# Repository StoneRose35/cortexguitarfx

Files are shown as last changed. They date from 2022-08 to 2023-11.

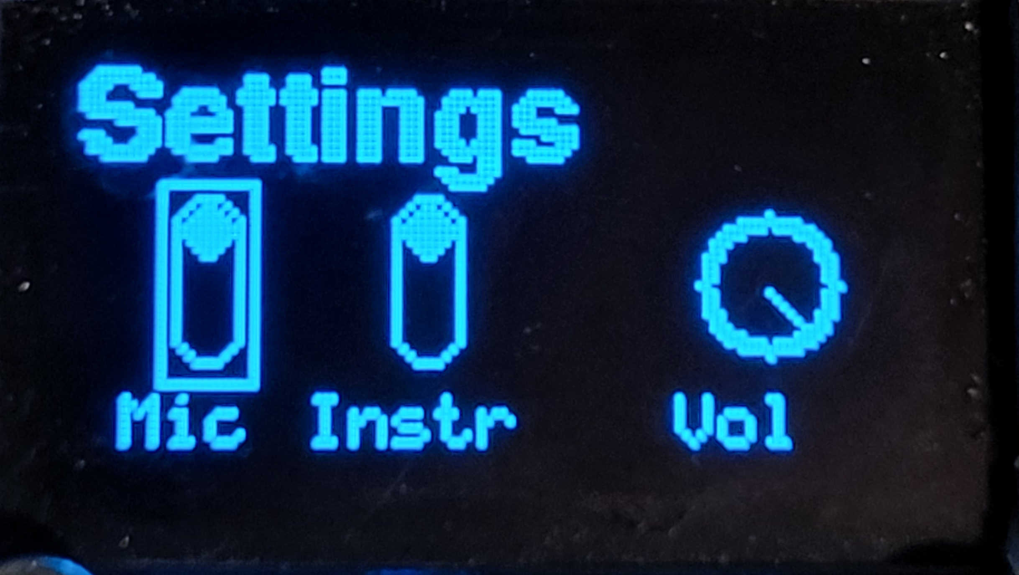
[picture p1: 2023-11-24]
Doc/manual/images/level5_select_settings_f.jpg

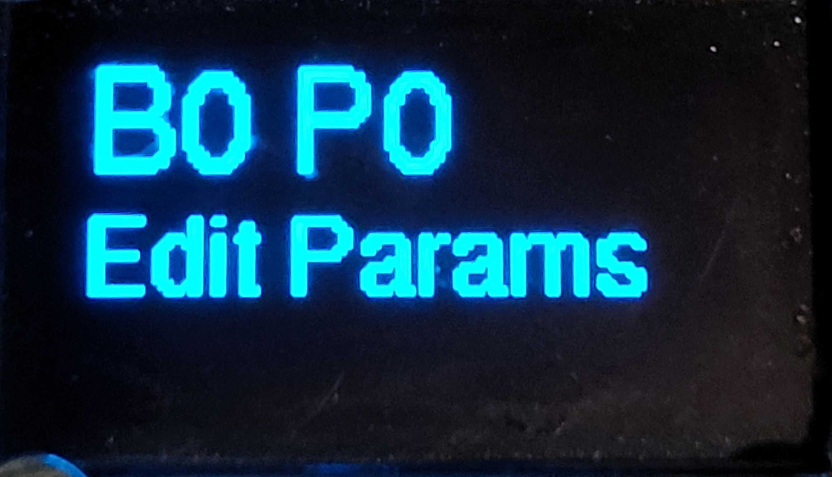
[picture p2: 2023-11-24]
Doc/manual/images/params_edit_f.jpg

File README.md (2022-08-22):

# cortexguitarfx
guitar effects processor implemented on various arm cortex platforms
Contains the following hardware elements:
* ARM Cortex M Microprocessor
* I2S Interface 
* Three potentiometers
* SSD1306-based 128x64 Pixel OLED Display
* Two pushbuttons: 'Enter' and 'Exit'
* rotary encoder
* analog pre- and postprocessor: guitar preamp and postgain amp

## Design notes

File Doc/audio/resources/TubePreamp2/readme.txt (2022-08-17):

Overdriven.fr - Free Guitar Cab Impulse Responses
-------------------------------------------------
This directory contains free guitar contains impulse responses from overdriven.fr (https://overdriven.fr). Visit https://overdriven.fr/overdriven/index.php/irdownloads/ for IR capture information.

Collection Version : 1.0

Cab 		: German 112 (1*12)
Speaker 	: Celestion(r) G12-65, 8 ohms
Power amp 	: KT88 
Mic preamp	: TubePreamp2

Microphones : 11
IR files    : 98

Microphones included : DYN-57 DYN-US-6 DYN-AT-1 DYN-AT-2 DYN-R20 RBN-DE-2 RBN-CN-1 RBN-CN-2 DYN-I5 DYN-7B DYN-CN-7 

Format is WAV 44,1 kHz, 32 bits floating point. IRs length is 50 milliseconds . 

Terms of use
------------
Overdriven.fr provides free audio impulse response files. These files remain the entire property of overdriven.fr / David. A. THESE FILES ARE PROVIDED « AS-IS ». overdriven.fr SHALL NOT BE LIABLE FOR ANY INDIRECT, SPECIAL, INCIDENTAL, CONSEQUENTIAL OR EXEMPLARY DAMAGES OR LOSSES ARISING FROM THE USE OF, INABILITY TO USE THE impulse response files. THESE EXCLUSIONS APPLY TO ANY CLAIMS FOR LOST PROFITS, LOST DATA, LOSS OF GOODWILL, WORK STOPPAGE, COMPUTER FAILURE OR MALFUNCTION, OR ANY OTHER COMMERCIAL DAMAGES OR LOSSES, EVEN IF OVERDRIVEN.FR KNEW OR SHOULD HAVE KNOWN OF THE POSSIBILITY OF SUCH DAMAGES 

Users are free to use these impulse files in the context of musical or video creations, free of rights, and this for any commercial or non-commercial purpose. 

It is expressly forbidden to host these files on other websites, or through any file sharing systems. Reselling these files is forbidden. Audio software or hardware vendors are not allowed to distribute these files with their products without a written agreement from the owner of overdriven.fr. 

Generated : dim. mars 06 16:51:21 CET 2022

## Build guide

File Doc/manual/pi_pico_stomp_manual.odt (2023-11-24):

PiPicoFX Stomp Manual

Overview

Analog Gain for Mic and Intrument

Quickdials (only functional in Live mode)

Output clipping

Input clipping

Screen

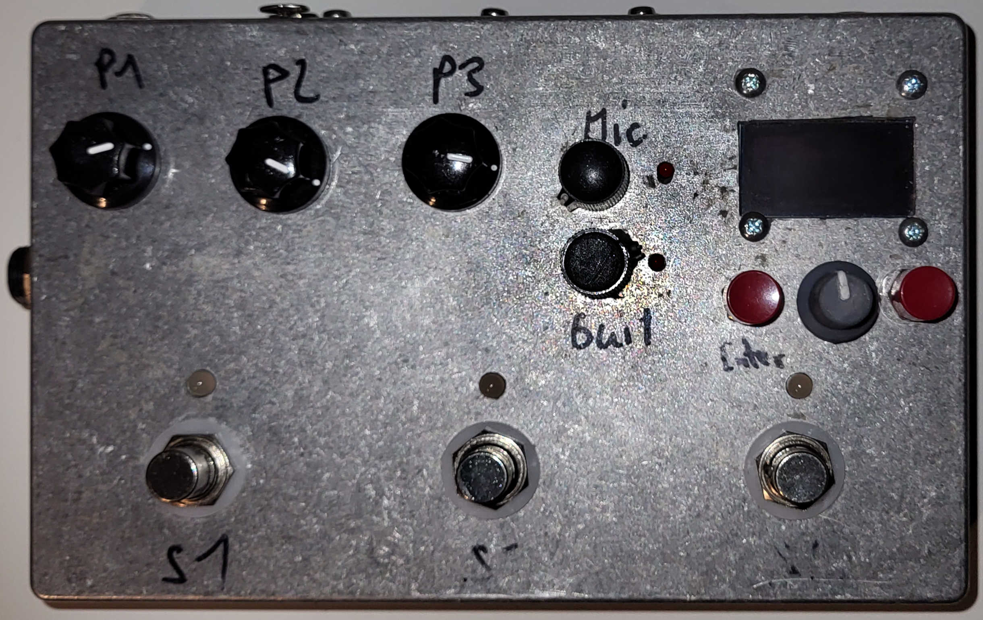
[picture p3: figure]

Power Connector

(12V~)

Stompswitches and LED’s

Enter

Exit

Rotary Dial

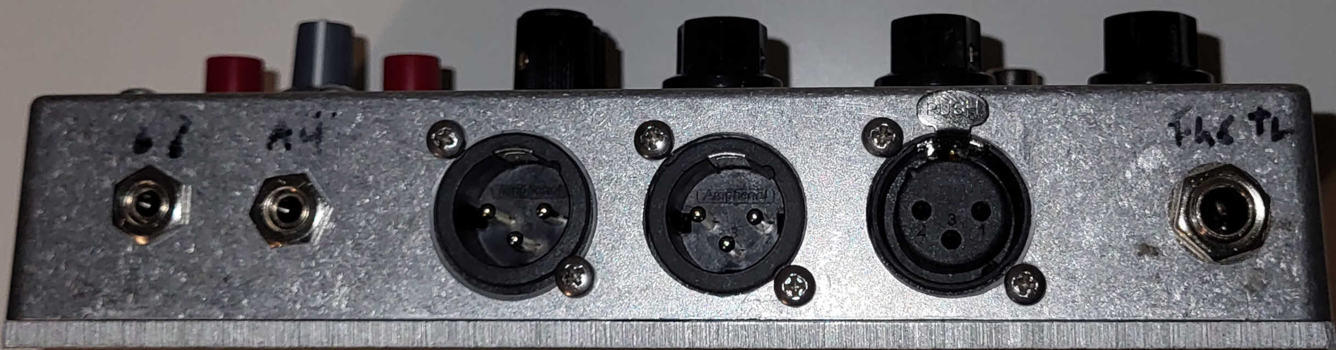
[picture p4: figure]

Phones Aux In Out R Out L Mic In (symm) Hi-Z In (unbal)

Quickstart (Live-Mode)

* Connect one or both XLR Outs to a Speaker or mixing desk

* Connect a microphone or instrument to an input

* Connect a 12 AC power supply to the barrel Jack

Use the Rotary Dial to change effect and the Quickdials to edit the first three parameters listed in that program.

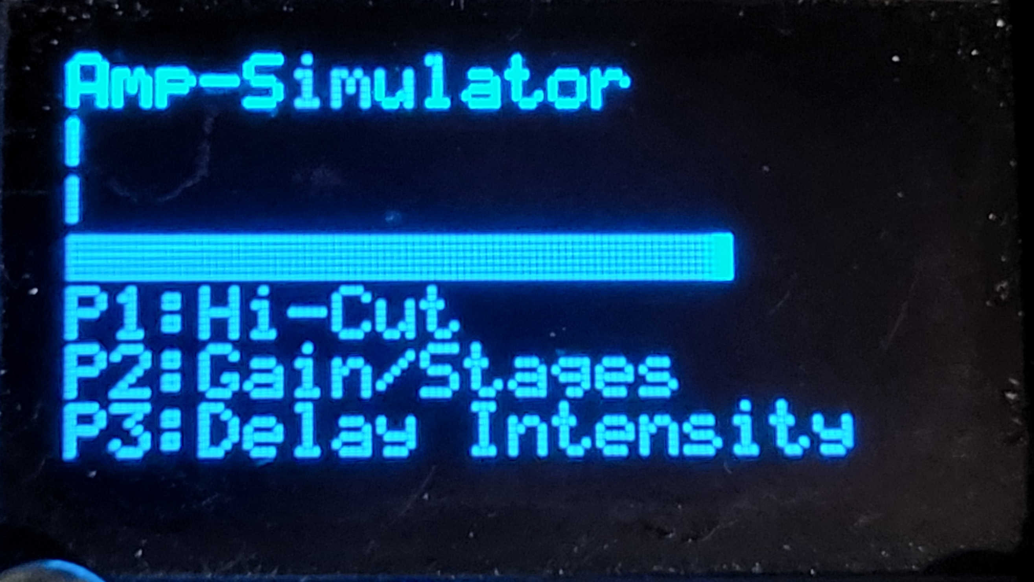
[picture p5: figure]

Effect name

Input Level

Output Level

CPU Load

Parameter assigned to P1

Parameter assigned to P2

Parameter assigned to P3

Edit more parameters

Press “Enter” to switch to the Parameter Edit Page, the rotary dial is used to browse through the parameters. Note that the first three Parameters are exclusively accessible through the Quickdials.

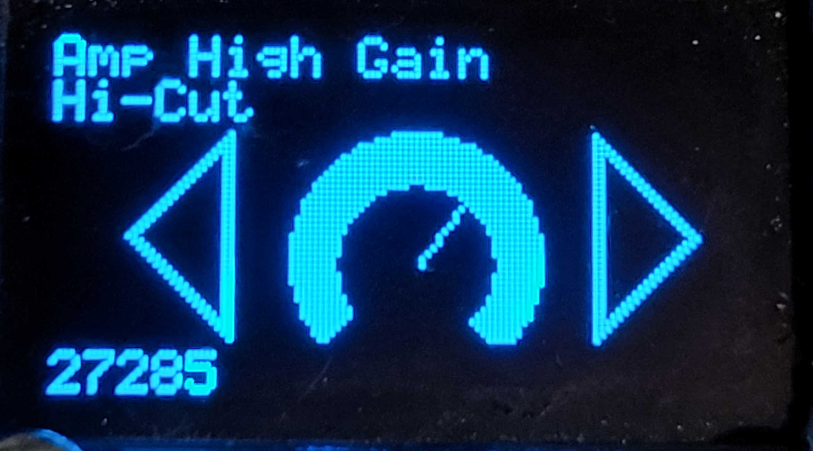
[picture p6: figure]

Effect Name

Parameter Name

“analog” display of current val

digital display of current val

To edit a certain parameter via rotary dial, press “Enter” again. The parameter value can the be changed using the rotary dial.

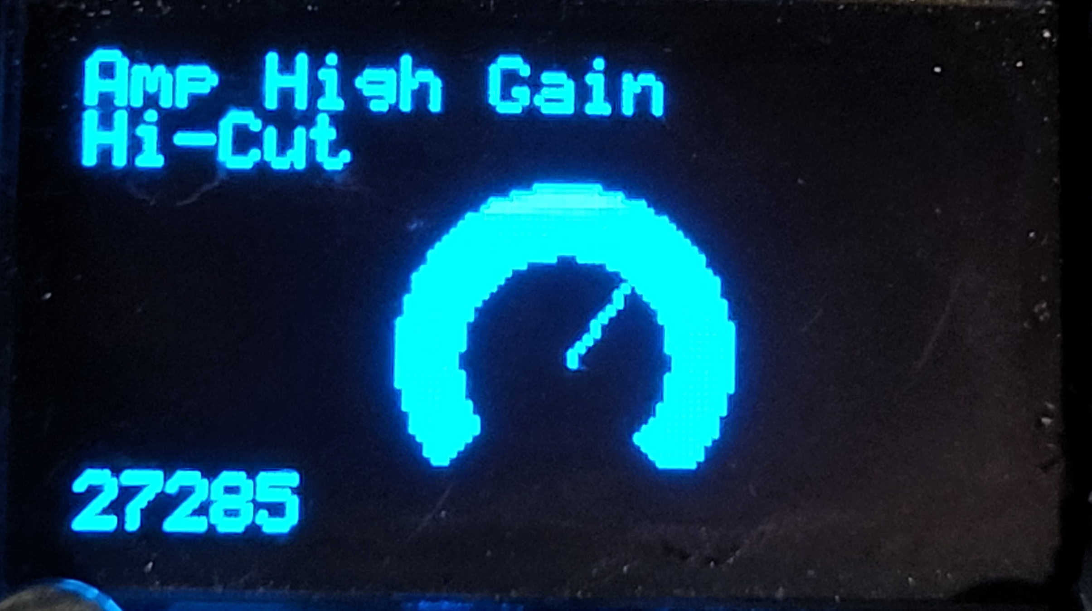
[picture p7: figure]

Presets

Press any of the stomp switches to enter preset mode. Presets are organized in banks of of three Presets, each one being accessible via the respective Stomp Switch.

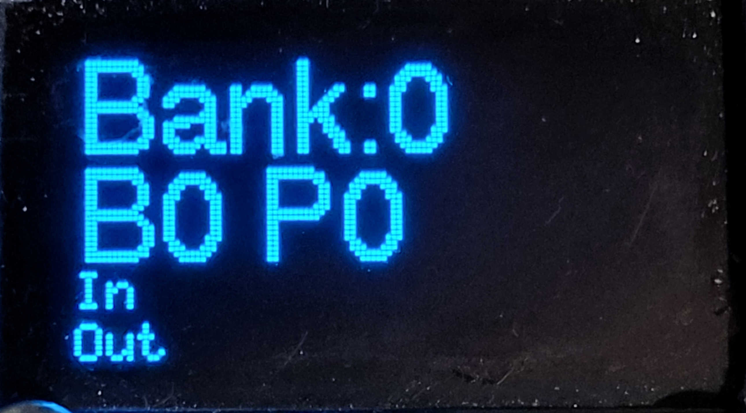
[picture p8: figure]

Bank Number

Name of the Preset

Input and Output

Level Indicators

A Preset consists of a Effect / Program with a fixed set of parameters.

Changing Presets: Tap the Stomp switch below an unlit LED to change to this Preset.

Changing Banks: Tap the left and middle Footswitch to lower the Bank, middle and right to

increase the bank. Note that changing bank does not change the preset

automatically

Edit a Preset

Press enter, navigate to the pen overlay (see below), and press Enter again

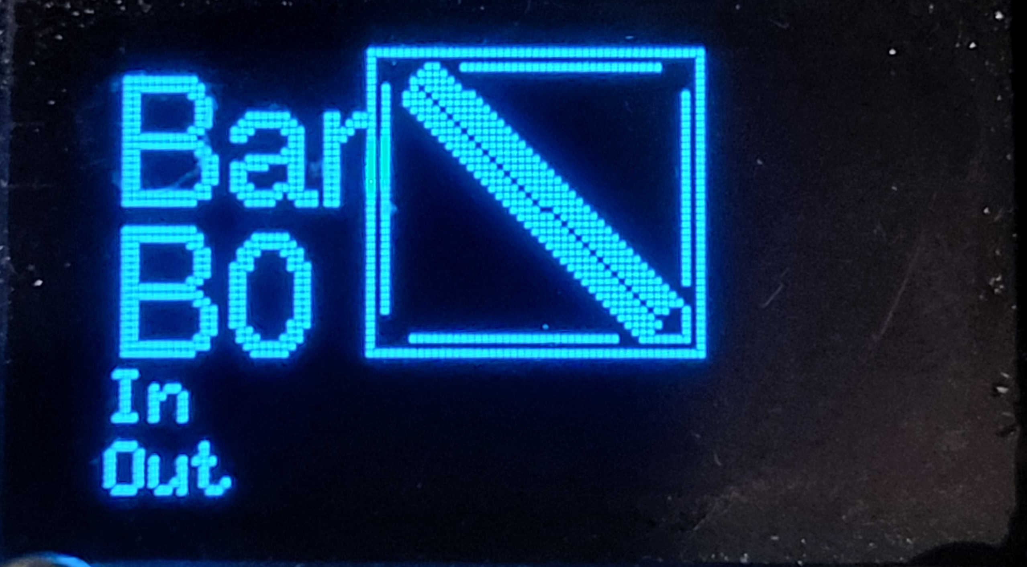
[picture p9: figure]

This activates the editing mode, currently indicated by the Preset Name in the top line.

Within the preset Editing Mode the following options can be chosen with the rotary dial

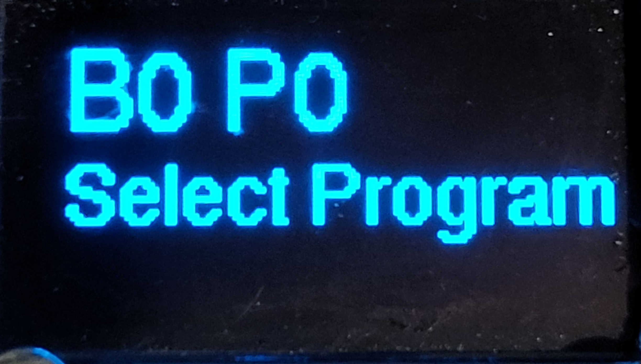
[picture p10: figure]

a) Select the effect / program, confirming with “Enter”

Changes to the Program selection mode. This is the

same as live mode except that the quickdials are

functionless.

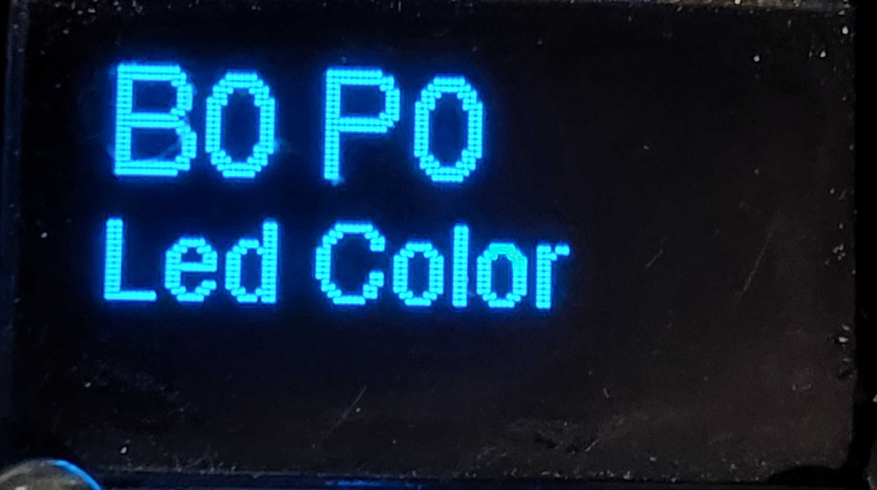
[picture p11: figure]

b) Change the LED Color, pressing Enter toggles

through the 3 available colors


c) Edit the Parameters of the given program,

confirming with “Enter” goes in the same mode

as parameter editing in live mode, except that

all parameters can be edited.

From Edit Mode, pressing Exit allows to return to Preset Mode, either by saving the edited preset or discarding and reverting the changes. This can be chosen by the rotary dial. Another tap on “Exit” confirms the choice and returns to the Preset Mode.

Settings

From Preset Mode choose the “mixer” overlay using the rotary dial, confirm with “Enter”.

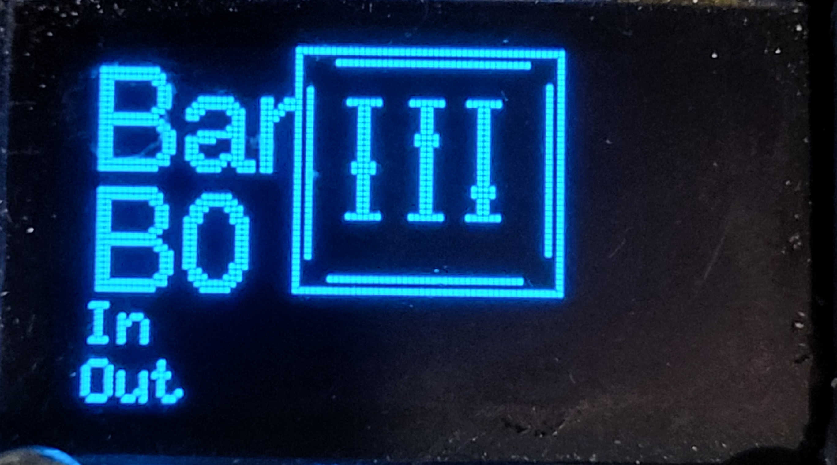
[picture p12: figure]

Within the Settings mode, the input can be switched on and off and the output volume can be controlled.


When a thin frame is displayed, the rotary dial chooses the parameter to edit. When a thick frame is displayed the actual change is made using the rotary dial.

One can go from selecting to editing via “Enter” and back using “Exit”.

Firmware Update

From Preset Mode choose the “chip” overlay using the rotary dial, confirm with “Enter”.

The screen goes off an the output clipping led is constantly lit (while no USB connection is made). This indicates the device is ready to have a new Firmware uploaded.

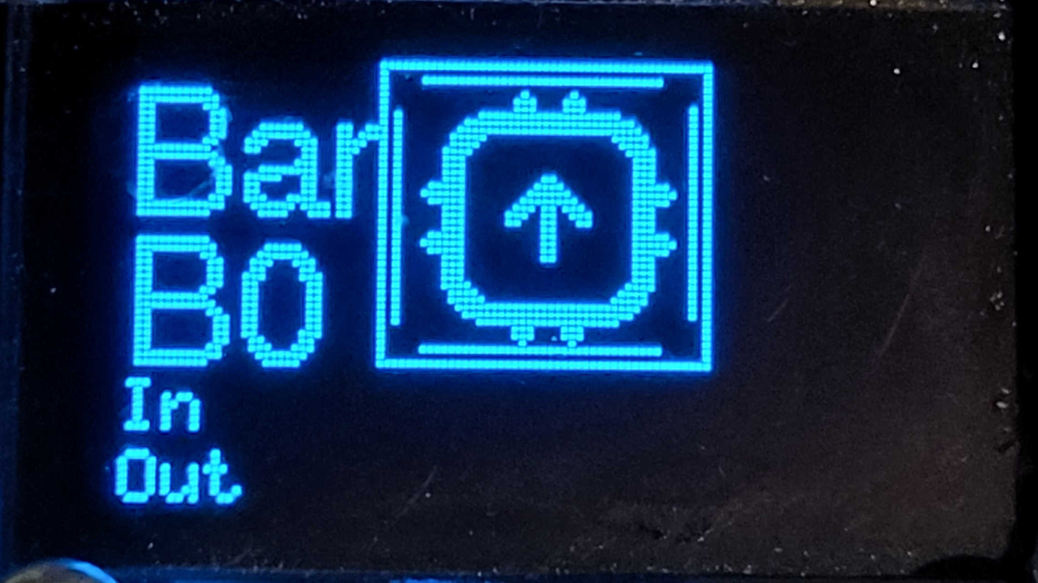
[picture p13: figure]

Connect the micro USB to a computer, then a usb drive named “RPI-RP2” (or similar), drag’n’drop the new firmware onto the drive. Upon Sucess the device restarts..

Technical Specs (known so far..)

* Outputs (symm): 5V max peak-to-peak

* Headphone Output: 200mW into 8Ohms

* Mic Input: differential pair 10kOhm input impedance

* Hi-Z Input: 1 MOhm input impedance

* Aux In: Stereo, 10 kOhm input impedance

* Power Supply: 12V AC, 500mA

* USB: for Firmware upgrade only

* Sampling rate: 48 kHz

* bit depth: 16bit

* Storage Banks: 100

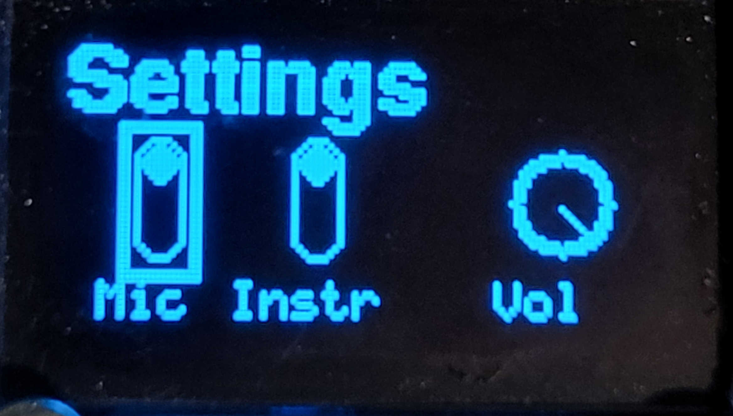
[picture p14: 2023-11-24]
Doc/manual/images/leve5_edit_settings_f.jpg

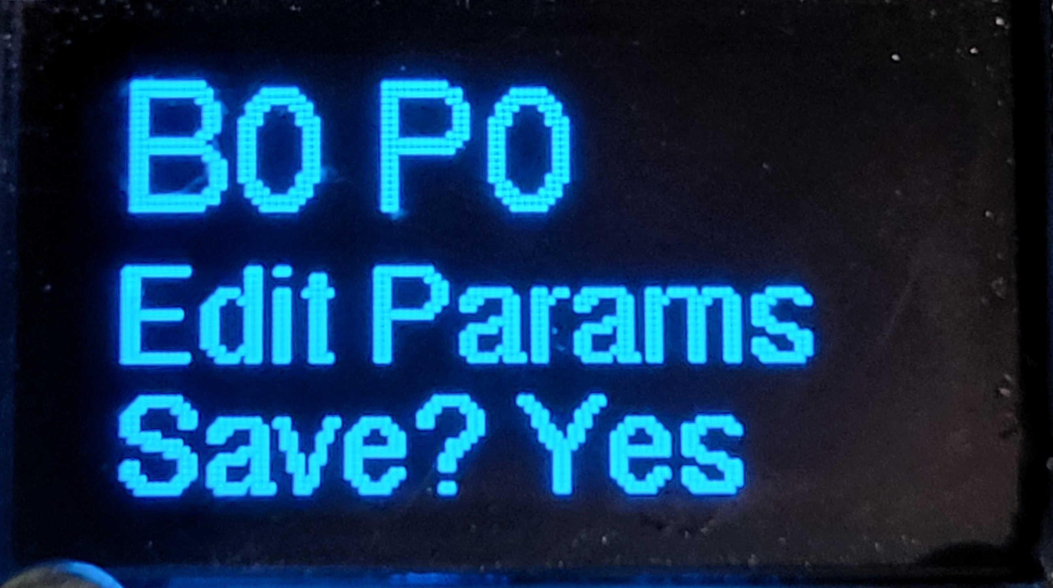
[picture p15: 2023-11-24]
Doc/manual/images/leve4_exit_save_f.jpg

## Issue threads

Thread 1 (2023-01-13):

Audio Codec Board

rohankeenoy, 2023-01-13:
Hello, I was just wondering which audio codec board you used for this project. I saw your video on youtube and am interested in the project. The schematics are otherwise very helpful.

Thank you

StoneRose35, 2023-04-13:
Hi, i used a custom designed board around a cs4270 codec, specifically for guitar i added a hi-z preamp stage. The gerber files are in the repo if you want to order a pcc for yourself.

tsatlook, 2023-05-02:
Hi, thank you for sharing the project!  I have tried to build the preamp board and I can't find the component for U4 and U5, it stated it is 78M05 for U4 and U5 but I can't find this size of 78M05. Could you tell me the type of the component for U4 and U5? Thank you so much.

StoneRose35, 2023-05-02:
Thank you for our interest in this project! For U4 and U5 you can use any SOT-23-3 (three pins) linear regulator. In my first batch i used the AP2120N for U4 and MCP1792T for U5.

tsatlook, 2023-05-04:
> Thank you for our interest in this project! For U4 and U5 you can use any SOT-23-3 (three pins) linear regulator. In my first batch i used the AP2120N for U4 and MCP1792T for U5.

Thank you so much!

fredrikcyber, 2024-02-11:
the oscillator that drives the cs4270 what frequency should it provide? Great project! I have already ordered the pcb and the 4270, only have the osc left.
Cheers and Thanks!
Fredrik

dwardman, 2024-10-10:
Hi StoneRose35, I uploaded guitarpreamp.kicad_pcb to OSH Park and it checked out except for one warning "Kicad processing does not update fill zones". It sounds like this relates to ground pours.  Did your board have this or can I ignore?

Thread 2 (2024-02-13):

oscillator frequency

fredrikcyber, 2024-02-13:
Great project, I am building it right now. The only thing I dont know is the frequency of the oscillator that drives the Codec.

Cheers and Thanks
Fredrik

StoneRose35, 2024-02-17:
Hi Frederik,

Sorry for the late reply.
The frequency of the oscillator is 12.288 MHz. The part i ordered was https://www.digikey.ch/de/products/detail/w%C3%BCrth-elektronik/831020465/13979363.

Cheers,
Philipp

fredrikcyber, 2024-02-17:
HiThanks for the reply!Is there anything that you have encountered that might be a problem in hardware or software? I am going to study the source code (I am a software developer by trade) to learn how to add more effects, so if there is any known bugs it would be interesting to hear about them and try to fix them! I can fork it or just send you updates. Thanks and Cheers!Fredrik Bergqvist Skickat från min iPad17 feb. 2024 kl. 09:01 skrev StoneRose35 ***@***.***>:
Hi Frederik,
Sorry for the late reply.
The frequency of the oscillator is 12.288 MHz. The part i ordered was https://www.digikey.ch/de/products/detail/w%C3%BCrth-elektronik/831020465/13979363.
Cheers,
Philipp

—Reply to this email directly, view it on GitHub, or unsubscribe.You are receiving this because you authored the thread.Message ID: ***@***.***>

StoneRose35, 2024-02-17:
Hi Fredrik
Thank you for your interest in this project!
Here are some thoughts regarding the software that might help you getting started. First off i'm not a professional software developer. So the software itself certainly doesn't follow standard pattern or rule. However there are some basic principle which i followed.
* architecture: "Bare-Metal" approach, i didn't include the c standard library, that's why there is no sprintf(),printf() for handling string manipulation. There are some bulky functions instead (in stringFunctions.h)
* architecture: no dynamic memory allocation except for the delay memory buffer.
* building: the project is makefile only, so if you wanna build on a windows platform you might need to adapt the Makefile
* branches: There are many of them, the most recent is "rp2040_stomp" which contains source for both the simple version without the stomp switches an the for full version with the stomp switches. The software version of the specific hardware can be set in "globalConfig.h".
* Adding new effects: Although the project is not very active i added a pitch shifter effect about a week ago, you might want to study the last two commits of "rp2040_stomp" to get an overview on what to do to add a new effects program.
* unused code: the codebase is very messy since i split it from a general purpose codebase used for various other application, such a light control (neopixel) and temperature and light control for an aquarium :-)
* bugs: certainly there are many. One i know of is that the rotary control for selecting the reverb characteristics in the reverb program skips a position when hitting one end and rotation back. You can either fork the repo or do pull requests, i try to approved in a timely manner.

cheers, philipp

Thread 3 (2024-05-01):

4 pin Oled Screen

mytokat8484, 2024-05-01:
Can you remake this for 4 pin ssd1306 or ssh1106 screens? thanks

StoneRose35, 2024-06-09:
What do you mean by 4 pins? Current ssd1306 is supported using SPI interface. Since no data is sent from the display to the mcu only 3 out of 4 pins are used.

roguestreak, 2024-10-31:
Sorry for the late join, I only just found your project; I believe the query is for the I2C screens rather than SPI, there are two common types of ssd1306 screen available, one has 4 pins and is I2C (2 pins I2C plus 2 pins power/ground), the other does SPI and has 7 pins (not sure of the layout).  Most arduino comments recommend the 4pin for I2C for simplicity, so if you have one of those on hand already you can't use it with an SPI-based code

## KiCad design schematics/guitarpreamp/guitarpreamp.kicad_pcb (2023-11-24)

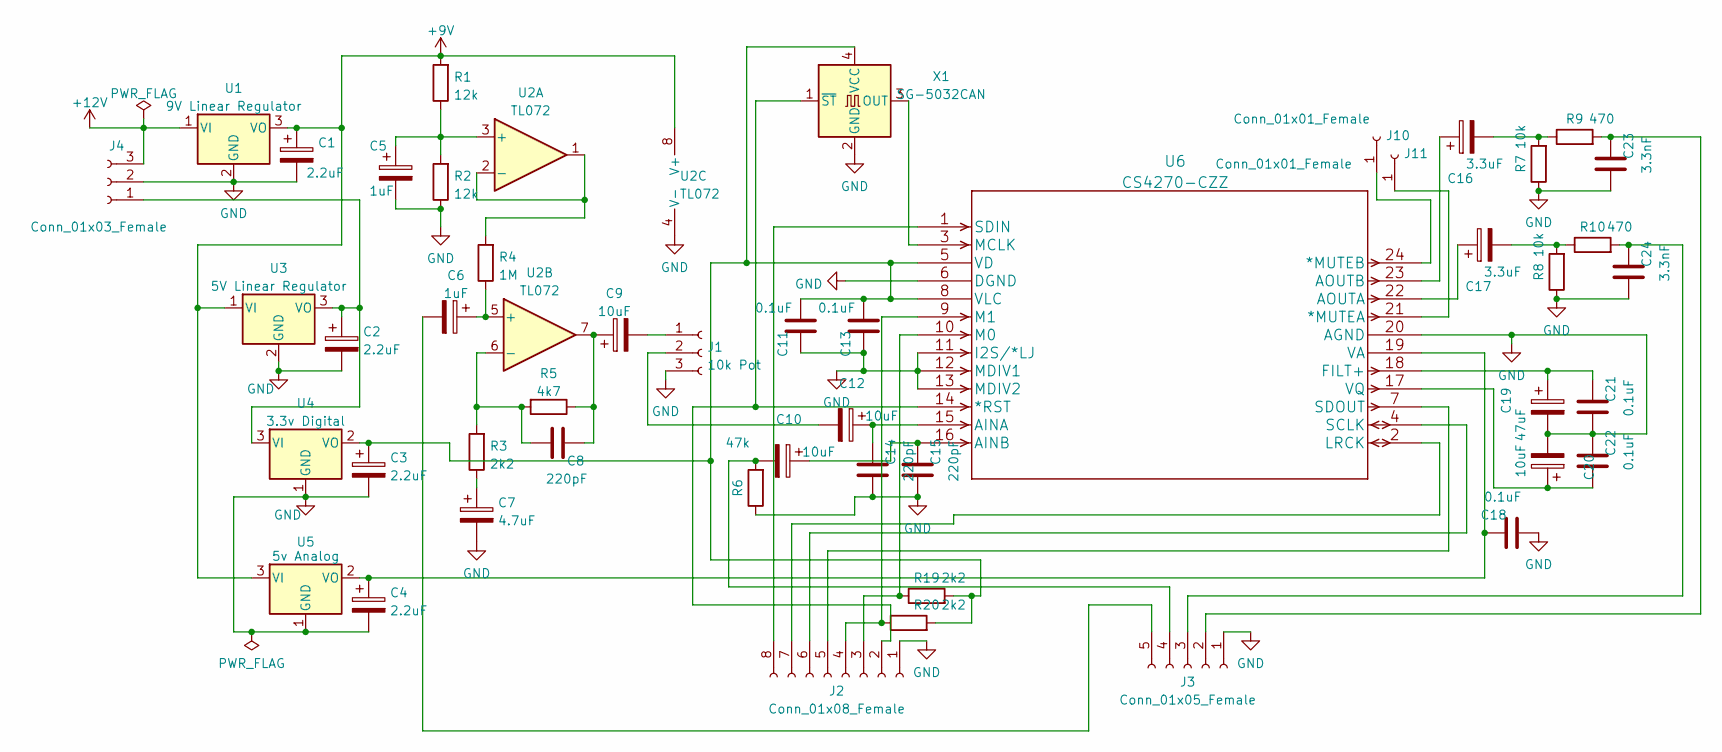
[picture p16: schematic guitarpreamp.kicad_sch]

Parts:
C1, C2, C3, C4: 2.2uF; CP_Elec_4x4.5
C5, C6: 1uF; CP_Elec_4x4.5
C7: 4.7uF; CP_Elec_4x4.5
C8, C14, C15: 220pF; C_0603_1608Metric_Pad1.08x0.95mm_HandSolder
C9, C10, C12, C20: 10uF; CP_Elec_4x4.5
C11, C13, C18, C21, C22: 0.1uF; C_1210_3225Metric_Pad1.33x2.70mm_HandSolder
C16, C17: 3.3uF; CP_Elec_4x4.5
C19: 47uF; CP_Elec_5x5.4
C23, C24: 3.3nF; C_0805_2012Metric_Pad1.18x1.45mm_HandSolder
J1: 10k Pot; PinHeader_1x03_P2.54mm_Vertical
J2: Conn_01x08_Female; PinHeader_1x08_P2.54mm_Vertical
J3: Conn_01x05_Female; PinHeader_1x05_P2.54mm_Vertical
J4: Conn_01x03_Female; PinHeader_1x03_P2.54mm_Vertical
J10, J11: Conn_01x01_Female; Pin_D0.7mm_L6.5mm_W1.8mm_FlatFork
R1, R2: 12k; R_0603_1608Metric_Pad0.98x0.95mm_HandSolder
R3, R19, R20: 2k2; R_0603_1608Metric_Pad0.98x0.95mm_HandSolder
R4: 1M; R_0603_1608Metric_Pad0.98x0.95mm_HandSolder
R5: 4k7; R_0603_1608Metric_Pad0.98x0.95mm_HandSolder
R6: 47k; R_0603_1608Metric_Pad0.98x0.95mm_HandSolder
R7, R8: 10k; R_0603_1608Metric_Pad0.98x0.95mm_HandSolder
R9, R10: 470; R_0603_1608Metric_Pad0.98x0.95mm_HandSolder
U1: 9V Linear Regulator; TO-252-2
U2: TL072; SOIC-8_3.9x4.9mm_P1.27mm
U3: 5V Linear Regulator; TO-252-2
U4: 3.3v Digital; SOT-23
U5: 5v Analog; SOT-23
U6: CS4270-CZZ; TSSOP-24_4.4x7.8mm_P0.65mm
X1: SG-5032CAN; Oscillator_SMD_SeikoEpson_SG8002CA-4Pin_7.0x5.0mm_HandSolde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

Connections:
+9V: C1.1, R1.2, U1.3 (VO), U2.8 (V+), U3.1 (VI), U5.3 (VI)
+12V: J4.3, U1.1 (VI)
GND: C1.2, C2.2, C3.2, C4.2, C5.2, C7.2, C11.2, C13.2, C14.1, C15.1, C18.1, C19.2, C20.2, C21.1, C22.2, C23.1, C24.1, J1.3, J2.1, J3.1, J4.2, R2.1, R6.1, R7.1, R8.1, U1.2 (GND), U2.4 (V-), U3.2 (GND), U4.1 (GND), U5.1 (GND), U6.6 (DGND), U6.11 (I2S/*LJ), U6.12 (MDIV1), U6.13 (MDIV2), U6.20 (AGND), X1.2 (GND)
unnamed: C2.1, J4.1, U3.3 (VO), U4.3 (VI)
unnamed: C5.1, R1.1, R2.2, U2.3 (+)
unnamed: C6.1, R4.1, U2.5 (+)
unnamed: C6.2, J3.5
unnamed: C7.1, R3.1
unnamed: C8.1, R3.2, R5.2, U2.6 (-)
unnamed: C8.2, C9.1, R5.1, U2.7
unnamed: C9.2, J1.1
unnamed: C10.1, C15.2, U6.16 (AINB)
unnamed: C10.2, J3.4, R6.2
unnamed: C3.1, C11.1, C13.1, R19.2, R20.2, U4.2 (VO), U6.5 (VD), U6.8 (VLC), X1.4 (VCC)
unnamed: C12.1, C14.2, U6.15 (AINA)
unnamed: C12.2, J1.2
unnamed: C16.1, U6.23 (AOUTB)
unnamed: C16.2, R7.2, R9.1
unnamed: C17.1, U6.22 (AOUTA)
unnamed: C17.2, R8.2, R10.1
unnamed: C4.1, C18.2, U5.2 (VO), U6.19 (VA)
unnamed: C19.1, C21.2, U6.18 (FILT+)
unnamed: C20.1, C22.1, U6.17 (VQ)
unnamed: C23.2, J3.2, R9.2
unnamed: C24.2, J3.3, R10.2
unnamed: J2.2, U6.14 (*RST), X1.1 (~ST)
unnamed: J2.3, R19.1, U6.10 (M0)
unnamed: J2.4, R20.1, U6.9 (M1)
unnamed: J2.5, U6.7 (SDOUT)
unnamed: J2.6, U6.4 (SCLK)
unnamed: J2.7, U6.2 (LRCK)
unnamed: J2.8, U6.1 (SDIN)
unnamed: J10.1, U6.24 (*MUTEB)
unnamed: J11.1, U6.21 (*MUTEA)
unnamed: R4.2, U2.1, U2.2 (-)
unnamed: U6.3 (MCLK), X1.3 (OUT)

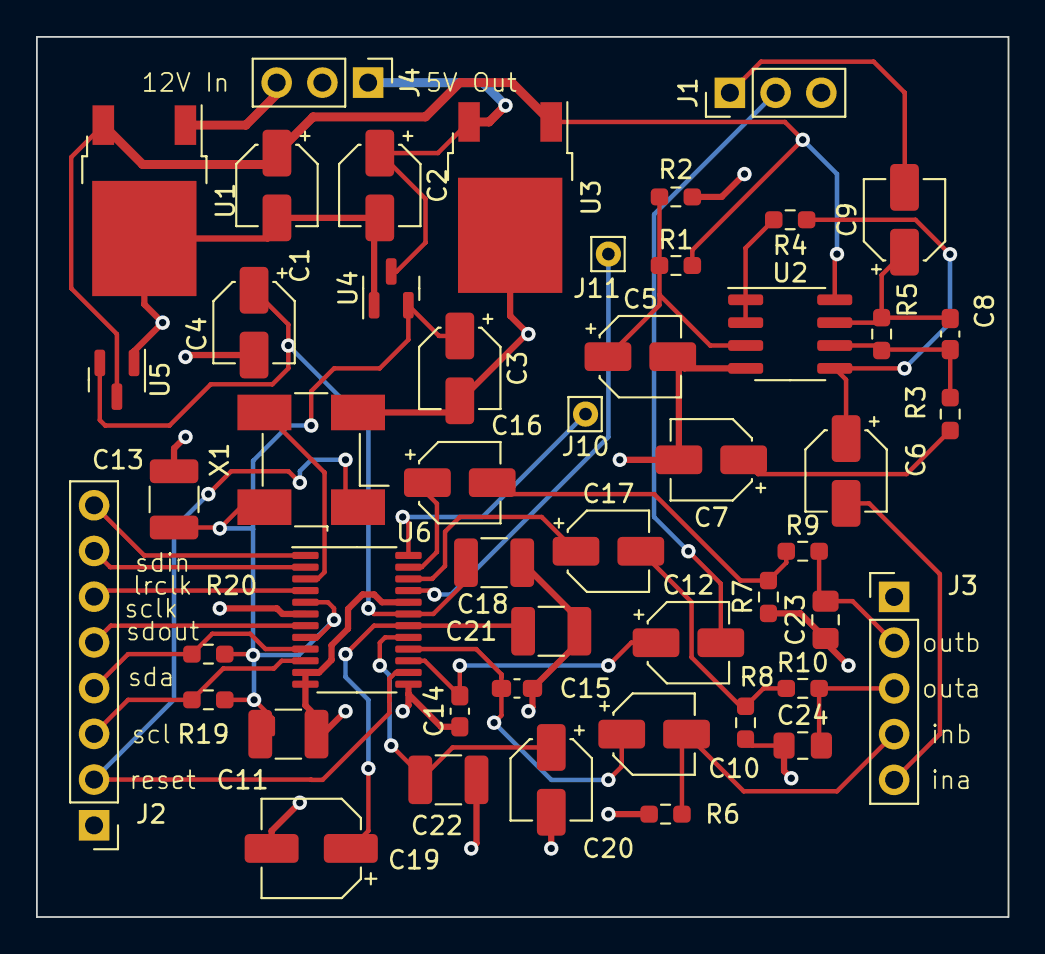
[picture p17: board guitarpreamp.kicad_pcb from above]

Board: 2 copper layers, 54.0 x 48.9 mm, 49 parts (0 on the bottom side), 36 nets.

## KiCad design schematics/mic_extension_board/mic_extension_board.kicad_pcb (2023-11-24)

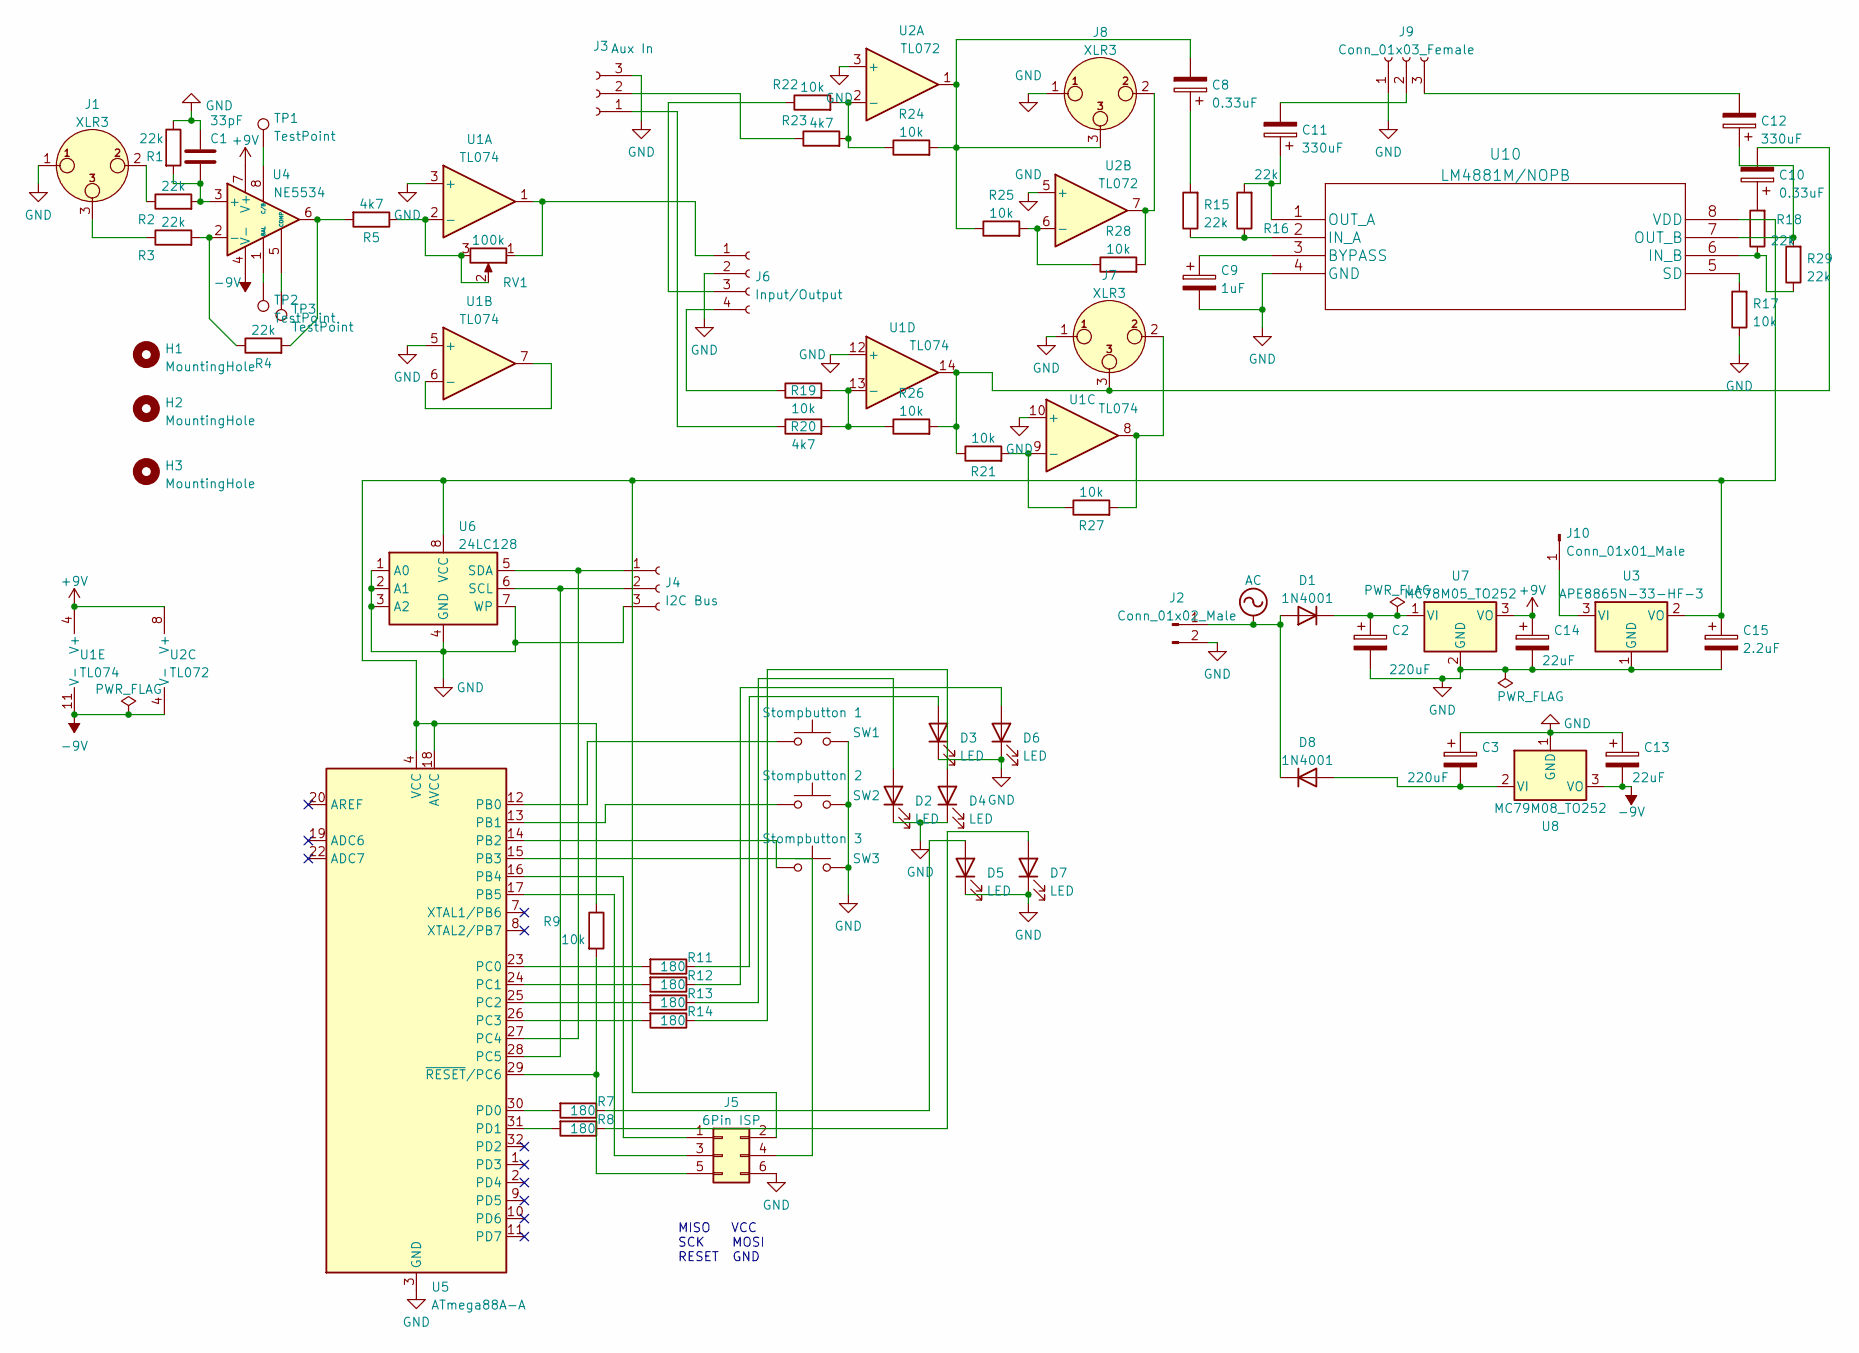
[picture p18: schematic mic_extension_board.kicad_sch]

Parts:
C1: 33pF; C_0603_1608Metric_Pad1.08x0.95mm_HandSolder
C2, C3: 220uF; CP_Elec_6.3x7.7
C8, C10: 0.33uF; CP_Elec_4x4.5
C9: 1uF; CP_Elec_4x4.5
C11, C12: 330uF; CP_Elec_6.3x7.7
C13, C14: 22uF; CP_Elec_4x4.5
C15: 2.2uF; CP_Elec_4x4.5
D1, D8: 1N4001; D_DO-41_SOD81_P10.16mm_Horizontal
D2, D3, D4, D5, D6, D7: LED; PinHeader_1x02_P2.54mm_Vertical
H1, H2, H3: MountingHole; MountingHole_3.2mm_M3
J1, J7, J8: XLR3; PinHeader_1x03_P2.54mm_Vertical
J2: Conn_01x02_Male; PinHeader_1x02_P2.54mm_Vertical
J3: Aux In; PinHeader_1x03_P2.54mm_Vertical
J4: I2C Bus; PinHeader_1x03_P2.54mm_Vertical
J5: 6Pin ISP; PinHeader_2x03_P2.54mm_Vertical
J6: Input/Output; PinHeader_1x04_P2.54mm_Vertical
J9: Conn_01x03_Female; PinHeader_1x03_P2.54mm_Vertical
J10: Conn_01x01_Male; PinHeader_1x01_P2.54mm_Vertical
R1, R2, R3, R4, R15, R16, R18, R29: 22k; R_0603_1608Metric_Pad0.98x0.95mm_HandSolder
R5, R20, R23: 4k7; R_0603_1608Metric_Pad0.98x0.95mm_HandSolder
R7, R8, R11, R12, R13, R14: 180; R_0603_1608Metric_Pad0.98x0.95mm_HandSolder
R9, R17, R19, R21, R22, R24, R25, R26, R27, R28: 10k; R_0603_1608Metric_Pad0.98x0.95mm_HandSolder
RV1: 100k; PinHeader_1x03_P2.54mm_Vertical
SW1: Stompbutton 1; PinHeader_1x02_P2.54mm_Vertical
SW2: Stompbutton 2; PinHeader_1x02_P2.54mm_Vertical
SW3: Stompbutton 3; PinHeader_1x02_P2.54mm_Vertical
TP1, TP2, TP3: TestPoint; TestPoint_Pad_D1.5mm
U1: TL074; SOIC-14_3.9x8.7mm_P1.27mm
U2: TL072; SOIC-8_3.9x4.9mm_P1.27mm
U3: APE8865N-33-HF-3; SOT-23
U4: NE5534; SOIC-8_3.9x4.9mm_P1.27mm
U5: ATmega88A-A; TQFP-32_7x7mm_P0.8mm
U6: 24LC128; SOIC-8_3.9x4.9mm_P1.27mm
U7: MC78M05_TO252; TO-252-2
U8: MC79M08_TO252; TO-252-2
U10: LM4881M/NOPB; SOIC-8_3.9x4.9mm_P1.27mm

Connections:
+9V: C14.1, U1.4 (V+), U2.8 (V+), U4.7 (V+), U7.3 (VO)
-9V: C13.2, U1.11 (V-), U2.4 (V-), U4.4 (V-), U8.3 (VO)
AC: D1.2 (A), D8.1 (K), J2.1
GND: C1.1, C2.2, C3.1, C9.2, C13.1, C14.2, C15.2, D2.1 (K), D3.1 (K), D4.1 (K), D5.1 (K), D6.1 (K), D7.1 (K), J1.1, J2.2, J3.3, J4.3, J5.6, J6.2, J7.1, J8.1, J9.1, R1.1, R17.1, SW1.2, SW2.2, SW3.2, U1.3 (+), U1.5 (+), U1.10 (+), U1.12 (+), U2.3 (+), U2.5 (+), U3.1 (GND), U5.3 (GND), U5.5 (GND), U5.21 (GND), U6.1 (A0), U6.2 (A1), U6.3 (A2), U6.4 (GND), U6.7 (WP), U7.2 (GND), U8.1 (GND), U10.4 (GND)
unnamed: C1.2, R1.2, R2.2, U4.3 (+)
unnamed: C2.1, D1.1 (K), U7.1 (VI)
unnamed: C8.1, R15.2
unnamed: C8.2, J8.3, R24.2, R25.1, U2.1
unnamed: C9.1, U10.3 (BYPASS)
unnamed: C10.1, R18.2
unnamed: C10.2, J7.3, R21.1, R26.2, U1.14
unnamed: C11.1, R16.2, U10.1 (OUT_A)
unnamed: C11.2, J9.2
unnamed: C12.1, R29.2, U10.7 (OUT_B)
unnamed: C12.2, J9.3
unnamed: C15.1, J5.2, R9.1, U3.2 (VO), U5.4 (VCC), U5.6 (VCC), U5.18 (AVCC), U6.8 (VCC), U10.8 (VDD)
unnamed: D2.2 (A), R13.1
unnamed: D3.2 (A), R11.1
unnamed: D4.2 (A), R14.1
unnamed: D5.2 (A), R7.1
unnamed: D6.2 (A), R12.1
unnamed: D7.2 (A), R8.1
unnamed: C3.2, D8.2 (A), U8.2 (VI)
unnamed: J1.2, R2.1
unnamed: J1.3, R3.1
unnamed: J3.1, R20.1
unnamed: J3.2, R23.1
unnamed: J4.1, U5.27 (PC4), U6.5 (SDA)
unnamed: J4.2, U5.28 (PC5), U6.6 (SCL)
unnamed: J5.1, U5.16 (PB4)
unnamed: J5.3, U5.17 (PB5)
unnamed: J5.4, U5.15 (PB3)
unnamed: J5.5, R9.2, U5.29 (~RESET/PC6)
unnamed: J6.1, RV1.1, U1.1
unnamed: J6.3, R22.1
unnamed: J6.4, R19.1
unnamed: J7.2, R27.2, U1.8
unnamed: J8.2, R28.2, U2.7
unnamed: J10.1, U3.3 (VI)
unnamed: R3.2, R4.1, U4.2 (-)
unnamed: R4.2, R5.2, U4.6
unnamed: R5.1, RV1.2, RV1.3, U1.2 (-)
unnamed: R7.2, U5.30 (PD0)
unnamed: R8.2, U5.31 (PD1)
unnamed: R11.2, U5.23 (PC0)
unnamed: R12.2, U5.24 (PC1)
unnamed: R13.2, U5.25 (PC2)
unnamed: R14.2, U5.26 (PC3)
unnamed: R15.1, R16.1, U10.2 (IN_A)
unnamed: R17.2, U10.5 (SD)
unnamed: R18.1, R29.1, U10.6 (IN_B)
unnamed: R19.2, R20.2, R26.1, U1.13 (-)
unnamed: R21.2, R27.1, U1.9 (-)
unnamed: R22.2, R23.2, R24.1, U2.2 (-)
unnamed: R25.2, R28.1, U2.6 (-)
unnamed: SW1.1, U5.12 (PB0)
unnamed: SW2.1, U5.13 (PB1)
unnamed: SW3.1, U5.14 (PB2)
unnamed: TP1.1, U4.8 (C/B)
unnamed: TP2.1, U4.1 (BAL)
unnamed: TP3.1, U4.5 (COMP)
unnamed: U1.6 (-), U1.7

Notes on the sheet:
MISO VCC SCK MOSI RESET GND

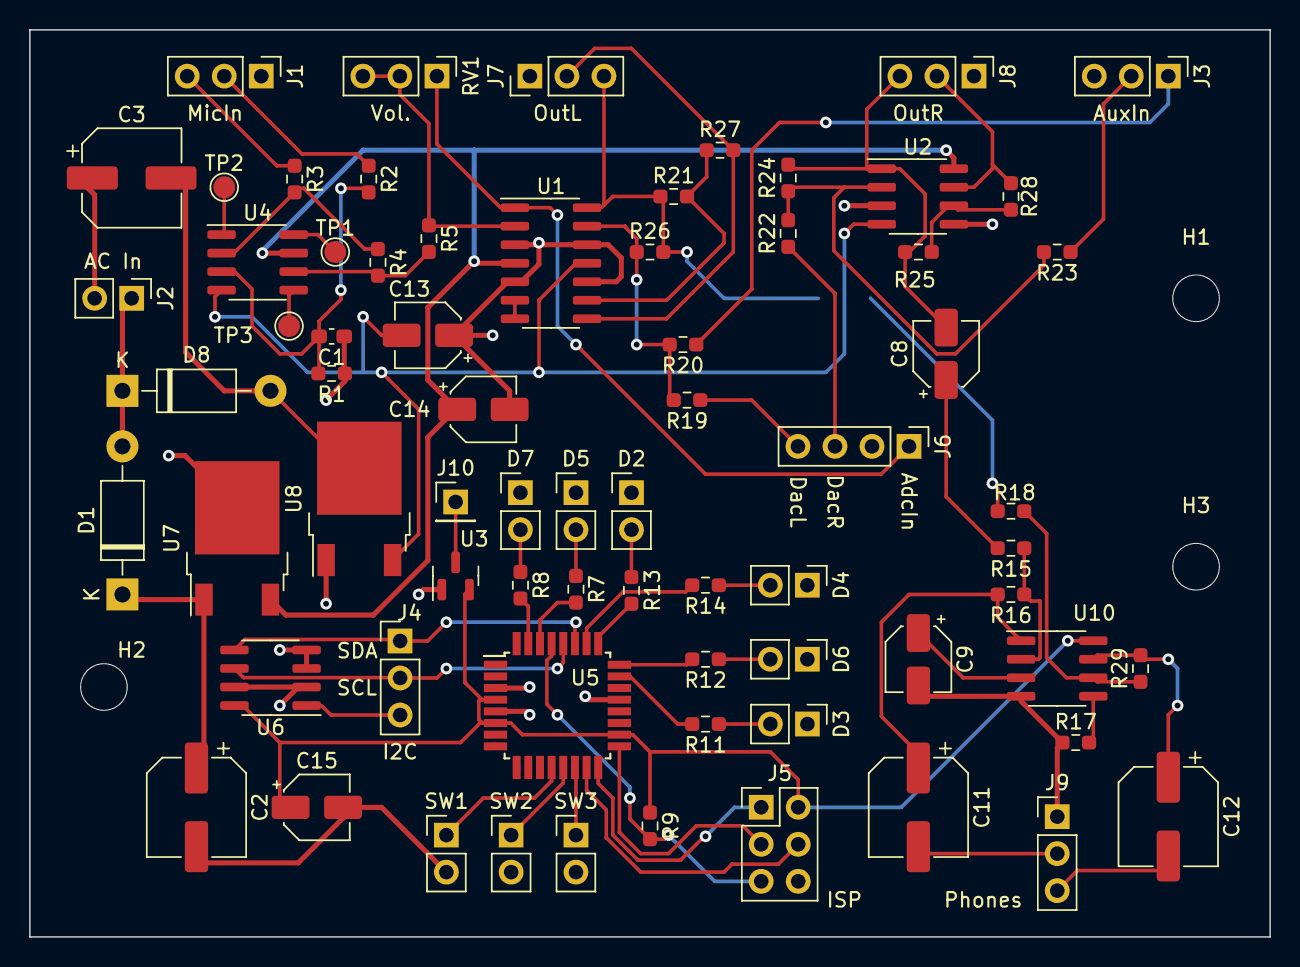
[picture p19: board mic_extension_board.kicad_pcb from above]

Board: 2 copper layers, 85.1 x 62.2 mm, 75 parts (1 on the bottom side), 62 nets.

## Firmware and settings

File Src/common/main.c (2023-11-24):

/**
 * \mainpage Ico Lamp Overview
 * \section archoverview Architectural Overview
 * The system contains two following basic components
 * \subsection comminterfaces Communication Interfaces
 * Two Uart Communication interfaces accessible through usb and bluetooth exposing a command line interface (CLI) or
 * and application programming interface (API). The interface type can be changed at runtime. The properties of the communication
 * interfaces are defined in bufferedInputStructs.h. The baudrate is defined in uart.h.
 * \subsection neopixeldriver Neopixel driver
 * A hardware-based neopixel driver allowing the transmission of a neopixel color array without interruption. This is typically
 * achieved with a DMA-fed timer or state machine.
 * \subsection fakebash Fake-Bash
 * The CLI features a defineable command history and basic cursor capabilities known from bash excluding autocompletion. 
 * The command line prefix is defined in consoleHandler.h
 * \image html ./timing_diagram_large.png
 * also see Doc/timing_diagram.svg
 * \section dataStructures Data Structures
 * Regarding the neopixel control the following data structures exists as singletons in the system.
 * * *rawdata* as a DMA-streamable array consumed by the hardware and converted from RGBStream by the neopixelDriver.c. This array
 * should never be manipulated by user code.
 * * *RGBStream* as a structures static or one-frame color information for all neopixels. Can be modified by user code. Note that editing these
 * values while the animation is running can have an unpredictable effect on the neopixel colors.
 * * *Tasks* as an animation definition. This structures should only be edited while the animation is not running.
 * \section commandref User Command Reference
 * \subsection colorCommands Color Command
 * `<COLOR>(neopixels)`
 * 
 * The following command exists which set a set of neopixel to a predefined color
 * * BACKGROUND
 * * FOREGROUND
 * * RED
 * * GREEN
 * * DARKBLUE
 * * LIGHTBLUE
 * * MAGENTA
 * * YELLOW
 * * ORANGE
 * * PURPLE
 * * YELLOWGREEN
 * * MEDIUMBLUE
 * * DARKYELLOW
 * * AQUA
 * * DARKPURPLE
 * * GRAY
 * The comand takes the neopixel set as an argument. Range declarations and direct indexes can ben combines freely.
 * Example AQUA(0-4,10) set the neopixel 0,1,2,3,4,10 to the color aqua.
 * \subsection rgbCommand RGB Command
 * `%RGB(Red,Green,Blue,neopixels)`
 * 
 * This command allow to set neopixels to a specific %RGB color value. The individual color values are in the range 0-255. Example %RGB(110,0,110,1,3,5-7) set the neopixels 1,3,5,6,7
 * to a dim violet.
 * \subsection startcommand Start Command
 * `START`
 * 
 * Starts the neopixel animation, if possible. 
 * \subsection stopcommand Stop Command
 * `STOP`
 * 
 * Stops the neopixel animation, if possible.
 * \subsection interpCommand Interpolator Setup Command
 * `INTERP(lamp_nr,nSteps,repeating)`
 * 
 * defines an interpolator/color sequence for neopixel lampnr, 
 * 255 means every lamp with nSteps steps, loops if repeating is 1, executes as one-shot if 0 . Example: INTERP(2,4,0)
 * defines an color sequence with 4 steps for neoppixel 2 which runs as a one-shot.
 * \subsection istepCommand Intepolator Step setup Command
 * `ISTEP(r,g,b,frames,interpolation,lampnr,step)`
 * 
 * r,g and b defines the color value from 0 to 255, frames define the number of frames it should take to display to 
 * color (if interplation is set constant) or to translate to the next color (if interpolation is linear). interpolation is 0 for
 * constant and 1 for linear. lampnr is the neopixel index starting from 0. step denotes the index in the steps array for which the color 
 * and duration should be set.
 * \subsection desciCommand Color Sequence / Interpolator description
 * `DESCI`
 * 
 * Print a description of a color sequences / interpolators including their progression. 
 * \subsection destroyCommand Destroy Color Sequence / Interpolator
 * `DESTROY(lampnr)`
 * 
  * lampnr: the neopixel whose interpolator should be destroyed, 255 for every neopixel/all interpolators.
 * \subsection npEngingeCommand Switch Neopixel Engine On/Off
 * `NPENGINGE(flag)`
 * 
 * switches the neopixel engine on or off, if off no interrupts are generated, the neopixel itself keeps the color last set.
 * off if flag is 0, on if flag is 1
 * \subsection saveCommand Save Command
 * `SAVE`
 * 
 * Save the current animation persistently. Can be loaded again using LOAD. Untested and probably not working in the Raspberry Pi Pico implementation.
 * \subsection loadCommand Load Command
 * `LOAD`
 * 
 * Loads an animation from persistent storage. Behaves unpredictable if not animation has been saved previously. Untested and probably not working in the Raspberry Pi Pico implementation.
 * \subsection apiCommand API Mode Command
 * `API`
 * 
 * Switches the current interface to API mode. This is typically used by a system interface such as the Android App also available in the project.
 * If this command is issued as a user the interface may suddenly appear unresponsive since the characters typed in are note echoed anymore.
 * In this case issue the Command "CONSOLE" to switch back to CLI/Console mode.
 * \subsection consoleCommand Console/CLI Mode Command
 * `CONSOLE`
 * 
 * Switches the current interface back to CLI mode. This command is useful in debugging cases or when the interface mode has been set to API erroneously.
 * \subsection setupbtCommand Setup Bluetooth Command
 * `SETUPBT`
 * 
 * Configures the HC-06 Bluetooth interface (Name, PIN and Baudrate) using AT-Commands. Not implemented in the Raspberry Pi Pico Version, Deprecated, will be removed in the future.
 * \subsection sysinfoCommand Sysinfo Command
 * `SYSINFO`
 * 
 *  
 */


/**
 * @file main.c
 * @author Philipp Fuerholz (fuerholz@gmx.ch)
 * @brief Entry Point for the Ico Lamp system
 * @version 0.1
 * @date 2021-12-22
 * ##Startup##
 * Assumes an initialized C runtime environment, this means 
 * * Stack Pointer is defined
 * * bss section i zero-initialized
 * * data section contains the values defined in the flash image
 * ##Main Function##
 * The main function is split into an initialization part run only once and a loop part running infinitly.
 * ###Initialization part###
 * In the initialization phase the following steps can be implemented
 * * clock setup: Set the CPU and bus clock according to the specific needs
 * * initialize the CPU itself, for example enable the floating point unit
 * * initialize communication interfaces: setting up the data structures is handled in a hardware-independent manner. A specific 
 *   implementation should provide initializers for the physical interface (initGpio) and the interrupt handlers for the communication interfaces
 *   (initUart and initBTUart)
 * * initialize the neopixel driver itself with initNeopixels
 * ###Main Loop###
 * The main loops processes a serie of tasks in a predefined order if they should be executed, these are
 * * send raw color data to the neopixel array
 * * handle usb CLI/API
 * * handle bluetooth CLI/API
 * * update Task array, e.g. compute the colors for the next frame
 * * convert RGBStream to streamable color data
 * * send one character over the usb Uart
 * * send one character over the bluetooth Uart
 */
#include "systemChoice.h"

#ifdef HARDWARE
#ifndef SIMPLE_TIMERTEST
#ifndef SIMPLE_NEOPIXEL


#include <drivers/neopixelDriver.h>
#include "hardware/regs/addressmap.h"
#include "hardware/regs/sio.h"
#include "hardware/rp2040_registers.h"
#include "system.h"
#include "drivers/core.h"
#include "drivers/systemClock.h"
#include "drivers/datetimeClock.h"
#include "drivers/systick.h"
#include "drivers/uart.h"
#include "consoleBase.h"
#include "drivers/dma.h"
#include "drivers/pio.h"
#include "drivers/adc.h"
#include "drivers/timer.h"
#include "drivers/gpio.h"
#include "drivers/oled_display.h"
#include "drivers/wm8731.h"
#include "usb/usb_common.h"
#include "usb/usb_cdc.h"
#include "drivers/cs4270_audio_codec.h"
#include "drivers/debugLed.h"
#include "consoleHandler.h"
#include "apiHandler.h"
#include "bufferedInputHandler.h"
#include "stringFunctions.h"
#include "fastExpLog.h"
#include "charDisplay.h"
#include "drivers/rotEncoderSwitchPower.h"
#include "cliApiTask.h"
#include "drivers/i2s.h"
#include "drivers/i2c.h"
#include "drivers/stompswitches.h"
#include "audio/sineplayer.h"
#include "audio/simpleChorus.h"
#include "audio/secondOrderIirFilter.h"
#include "audio/firFilter.h"
#include "audio/waveShaper.h"
#include "audio/oversamplingWaveshaper.h"
#include "drivers/multicore.h"
#include "core1Main.h"
#include "pipicofx/fxPrograms.h"
#include "pipicofx/pipicofxui.h"

volatile uint32_t task=0;
volatile uint8_t context;


CommBufferType usbCommBuffer __attribute__((aligned (256)));
ConsoleType usbConsole;
ApiType usbApi;
BufferedInputType bufferedInput;
//CommBufferType btCommBuffer;


PiPicoFxUiType piPicoUiController;
uint32_t core1Handshake;
volatile int16_t avgOutOld=0,avgInOld=0;
volatile uint16_t bufferCnt=0;
volatile uint8_t fxProgramIdx = 1;
volatile uint32_t ticStart,ticEnd,cpuLoad;
volatile uint8_t programsActivated=0;
const uint8_t stompswitch_progs[]={8,7,1};
volatile uint8_t programsToInitialize[3];
FxPresetType presets[3];
volatile uint8_t currentBank=0;
volatile uint8_t currentPreset=0;

// 0: done
// 1: change request
// 2: fade out
// 3: in bypass / change in progress
// 4: fade in
volatile uint8_t programChangeState;
#define UI_UPDATE_IN_SAMPLE_BUFFERS 300
#define AVERAGING_LOWPASS_CUTOFF 10

volatile uint16_t secCnt=0;

char charbfr[8];
/**
 * @brief the main entry point, should never exit
 * 
 * @return int by definition but should never return a value
 */
int main(void)
{


	/*
	 *
	 * Initialize Hardware components
	 * 
	 * */
	#ifdef STM32
	enableFpu();
	#endif
    setupClock();
	initUsbPll();
	initSystickTimer();
	initDMA();
	initGpio();
	initPio();
	initTimer();
	initAdc();
	initDatetimeClock();
	#ifdef WM8731
	initI2c(26);
	#endif
	#ifdef CS4270
	initI2c(CS4270_I2C_ADDRESS); //72 
	#endif
	#ifdef WM8731
	setupWm8731(SAMPLEDEPTH_16BIT,SAMPLERATE_48KHZ);
	#endif
	#ifdef CS4270
	setupCS4270();
#endif
	startCore1(&core1Main);
	// sync with core 1
	while ((*SIO_FIFO_ST & (1 << SIO_FIFO_ST_VLD_LSB)) != (1 << SIO_FIFO_ST_VLD_LSB));
	core1Handshake=*SIO_FIFO_RD;
	while (core1Handshake != 0xcafeface)
	{
		DebugLedOn();
		core1Handshake = *SIO_FIFO_RD;
	}





	//initUSB();
	//initUart(57600,&usbCommBuffer);

	/*
	 *
	 * Initialise Component-specific drivers
	 * 
	 * */


	initOledDisplay();

	initDebugLed();


	/*
     *
     * Initialize Background Services
     *
	 */

	
	piPicoFxUiSetup(&piPicoUiController);
	OledClearDisplay();
	for (uint8_t c=0;c<N_FX_PROGRAMS;c++)
	{
		if ((uint32_t)fxPrograms[c]->setup != 0)
		{
			fxPrograms[c]->setup(fxPrograms[c]->data);
		}
	}
	enterLevel0(&piPicoUiController);
	initCliApi(&bufferedInput,&usbConsole,&usbApi,&usbCommBuffer,sendCharAsyncUsb);




	ticEnd=0;
	ticStart=0;
	programsToInitialize[0]=0xFF;

	#ifdef WM8731
	initI2SSlave();
	#else
	initI2SSlave();
	#endif
    /* Loop forever */
	for(;;)
	{

		if (bufferCnt >= UI_UPDATE_IN_SAMPLE_BUFFERS)
		{
			bufferCnt = 0;
			task |= (1 << TASK_UPDATE_AUDIO_UI);
		}
		//cliApiTask(&bufferedInput);
	}
}
#endif
#endif
#endif

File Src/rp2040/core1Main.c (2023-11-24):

#include "globalConfig.h"
#include "system.h"
#include "drivers/dma.h"
#include "drivers/multicore.h"
#include "core1Main.h"
#include "drivers/gpio.h"
#include "drivers/irq.h"
#include "drivers/oled_display.h"
#include "audio/firFilter.h"
#include "audio/audiotools.h"
#include "audio/delay.h"
#include "pipicofx/fxPrograms.h"
#include "pipicofx/pipicofxui.h"
#include "pipicofx/picofxCore.h"
#include "drivers/adc.h"
#include "stringFunctions.h"
#include "drivers/rotEncoderSwitchPower.h"
#include "drivers/stompswitches.h"
#include "drivers/systick.h"
#include "hardware/regs/addressmap.h"
#include "hardware/regs/sio.h"
#include "hardware/regs/m0plus.h"
#include "hardware/rp2040_registers.h"


int16_t firstHalfOut;
FirFilterType**core1FirData;
extern volatile uint32_t task;
extern volatile int16_t avgOutOld,avgInOld;
extern volatile uint8_t fxProgramIdx;
extern volatile uint32_t cpuLoad;
extern volatile uint8_t programsActivated;
extern volatile uint8_t programChangeState;
extern volatile uint8_t programsToInitialize[3];
extern const uint8_t stompswitch_progs[];
extern PiPicoFxUiType piPicoUiController;
int16_t avgOldOutBfr;
int16_t avgOldInBfr;
uint8_t cpuLoadBfr;
int16_t encoderDelta;
uint8_t switchVals[2]={0,0};
//PiPicoFxUiType uiControllerData;
uint16_t adcChannelOld0=0,adcChannel0=0;
uint16_t adcChannelOld1=0,adcChannel1=0;
uint16_t adcChannelOld2=0,adcChannel2=0;
uint16_t adcChannel=0;
uint8_t stompSwitchState;
FxPresetType preset1, preset2;



static volatile uint32_t * audioStatePtr;
#define UI_DMIN 1
#define ADC_LOWPASS 2

const uint8_t switchesPins[2]={ENTER_SWITCH,EXIT_SWITCH};

void isr_c1_sio_irq_proc1_irq16() // only fires when a fir computation has to be made
{
    if ((*SIO_FIFO_ST & (1 << SIO_FIFO_ST_VLD_LSB))!= 0)
    {
        core1FirData = (FirFilterType**)*SIO_FIFO_RD;
        firstHalfOut = processFirstHalf(*core1FirData);
        *SIO_FIFO_WR = firstHalfOut;
    }
    else if (((*SIO_FIFO_ST & (1 << SIO_FIFO_ST_ROE_LSB)) != 0) || ((*SIO_FIFO_ST & (1 << SIO_FIFO_ST_WOF_LSB)) != 0))
    {
        *SIO_FIFO_ST = (1 << 2);
    }
}

void core1Main()
{
    audioStatePtr = getAudioStatePtr();

    // initalized the rotary encoder and the switches so that core 1 handler the interrupts of the ui elements
    initRotaryEncoder(switchesPins,2);
    #ifdef EXTENSION_BOARD
    initStompSwitchesInterface();
    #endif
    initRoundRobinReading(); // internal adc for reading parameters

    setAsOuput(CLIPPING_LED_INPUT);
    setAsOuput(CLIPPING_LED_OUTPUT);

    #ifdef EXTENSION_BOARD
    setStompswitchColorRaw(0);
    #endif

    *SIO_FIFO_ST = (1 << 2);
    *SIO_FIFO_WR=0xcafeface; // write sync word for core 0 to wait for core 1
    *NVIC_ISER = (1 << 16) | (1 << 11); // enable interrupt for dma and sio of proc1 
    setInterruptPriority(11,1);
    /*
    preset1.bankNr = 0;
    preset1.bankPos = 1;
    preset1.name[0]=0;
    appendToString(preset1.name,"ShortRev");
    preset1.programNr = 8;
    preset1.parameters[0]=2222;
    preset1.parameters[1]=2568;
    preset1.parameters[2]=0;
    savePreset(&preset1,0);
    waitSysticks(10);
    loadPreset(&preset2,0);
    waitSysticks(10);
    */

    for(;;)
    {
        if ((task & (1 << TASK_UPDATE_POTENTIOMETER_VALUES)) == (1 << TASK_UPDATE_POTENTIOMETER_VALUES))
        {
            // call the update function of the chosen program
            adcChannel = getChannel0Value();
            adcChannel0 = adcChannel0 + ((ADC_LOWPASS*(adcChannel - adcChannel0)) >> 8);
            if ((adcChannel0 > adcChannelOld0) && (adcChannel0-adcChannelOld0) > UI_DMIN )
            {
                onKnob0(adcChannel0,&piPicoUiController);
                adcChannelOld0=adcChannel0;
            }
            else if ((adcChannel0 < adcChannelOld0) && (adcChannelOld0-adcChannel0) > UI_DMIN )
            {
                onKnob0(adcChannel0,&piPicoUiController);
                adcChannelOld0=adcChannel0;
            }

            adcChannel = getChannel1Value();
            adcChannel1 = adcChannel1 + ((ADC_LOWPASS*(adcChannel - adcChannel1)) >> 8);
            if ((adcChannel1 > adcChannelOld1) && (adcChannel1-adcChannelOld1) > UI_DMIN )
            {
                onKnob1(adcChannel1,&piPicoUiController);
                adcChannelOld1=adcChannel1;
            }
            else if ((adcChannel1 < adcChannelOld1) && (adcChannelOld1-adcChannel1) > UI_DMIN )
            {
                onKnob1(adcChannel1,&piPicoUiController);
                adcChannelOld1=adcChannel1;
            }

            adcChannel = getChannel2Value();
            adcChannel2 = adcChannel2 + ((ADC_LOWPASS*(adcChannel - adcChannel2)) >> 8);
            if ((adcChannel2 > adcChannelOld2) && (adcChannel2-adcChannelOld2) > UI_DMIN )
            {
                onKnob2(adcChannel2,&piPicoUiController);
                adcChannelOld2=adcChannel2;
            }
            else if ((adcChannel2 < adcChannelOld2) && (adcChannelOld2-adcChannel) > UI_DMIN )
            {
                onKnob2(adcChannel2,&piPicoUiController);
                adcChannelOld2=adcChannel;
            }
            task &= ~(1 << TASK_UPDATE_POTENTIOMETER_VALUES);
        }
        if ((task & (1 << TASK_UPDATE_AUDIO_UI)) == (1 << TASK_UPDATE_AUDIO_UI))
        {
            avgOldInBfr = avgInOld >> 8;
            avgOldOutBfr = avgOutOld >> 8;
            cpuLoadBfr = (cpuLoad >> 1);
            onUpdate(avgOldInBfr,avgOldOutBfr,cpuLoadBfr,&piPicoUiController);
            if ((*audioStatePtr & (1 << AUDIO_STATE_INPUT_CLIPPED)) == (1 << AUDIO_STATE_INPUT_CLIPPED))
            {
                setPin(CLIPPING_LED_INPUT,1);
                *audioStatePtr &= ~(1 << AUDIO_STATE_INPUT_CLIPPED);
            }
            else
            {
                setPin(CLIPPING_LED_INPUT,0);
            }
            if ((*audioStatePtr & (1 << AUDIO_STATE_OUTPUT_CLIPPED)) == (1 << AUDIO_STATE_OUTPUT_CLIPPED))
            {
                setPin(CLIPPING_LED_OUTPUT,1);
                *audioStatePtr &= ~(1 << AUDIO_STATE_OUTPUT_CLIPPED);
            }
            else
            {
                setPin(CLIPPING_LED_OUTPUT,0);
            }
            task &= ~(1 << TASK_UPDATE_AUDIO_UI);
        }

        /*
         *
         * UI Switches Callback
         * 
        */
        switchVals[0] = getSwitchValue(0);
        if ((switchVals[0] & 1) > 0)
        {
            onEnterPressed(&piPicoUiController);
            clearPressedStickyBit(0);
        }
        if((switchVals[0] & 2) > 0)
        {
            onEnterReleased(&piPicoUiController);
            clearReleasedStickyBit(0);
        }

        switchVals[1] = getSwitchValue(1);
        if ((switchVals[1] & 1) > 0)
        {
            onExitPressed(&piPicoUiController);
            clearPressedStickyBit(1);
        }
        if ((switchVals[1] & 2) > 0)
        {
            onExitReleased(&piPicoUiController);
            clearReleasedStickyBit(1);
        }
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

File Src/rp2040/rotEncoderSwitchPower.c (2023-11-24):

#include "drivers/rotEncoderSwitchPower.h"
#include "hardware/regs/addressmap.h"
#include "hardware/regs/io_bank0.h"
#include "hardware/regs/pads_bank0.h"
#include "hardware/regs/m0plus.h"
#include "hardware/regs/sio.h"
#include "hardware/rp2040_registers.h"
#include "drivers/cs4270_audio_codec.h"
#include "drivers/timer.h"
#include "drivers/systick.h"
#include "drivers/irq.h"

static uint32_t oldtickenc,oldtickswitch;
static volatile uint32_t encoderVal = 0x7FFFFFFF;
static volatile uint32_t encoderValOld = 0x7FFFFFFF;
static volatile int16_t encoderStickyIncrement=0;
static volatile int16_t encoderStickyDecrement=0;
static volatile uint32_t currentUsVal;
static volatile uint32_t lastUsVal;
static volatile uint8_t switchVal;
static volatile uint8_t switchPins[8];
static volatile uint8_t switchVals[8]; // bit 0: sticky bit set when button is pressed (chage from 0 to 1), bit 1: sticky bit set when button is released, bit 2: momentary value
static volatile uint32_t oldTickSwitches[8];
static volatile uint8_t lastTrigger;
void isr_c1_io_irq_bank0_irq13()
{
    uint32_t* switchIntAddress;
    if ((*ENCODER_1_INTR & (1 << ENCODER_1_EDGE_HIGH)) == (1 << ENCODER_1_EDGE_HIGH))
    {
        *ENCODER_1_INTR |= (1 << ENCODER_1_EDGE_HIGH);
        if(lastTrigger == 1)
        {
            if ((*GPIO_IN & (1 << ENCODER_2)) == (1 << ENCODER_2)) 
            { 
                encoderVal--;
                if (encoderValOld > encoderVal+1)
                {
                    encoderStickyDecrement++;
                    encoderValOld=encoderVal;
                    lastUsVal = currentUsVal;
                    currentUsVal = getTimeLW();
                }
            }
            else
            { 
                encoderVal++;
                //encoderStickyIncrement++;
            }
        }
        lastTrigger = 0;
    }
    else if ((*ENCODER_1_INTR & (1 << ENCODER_1_EDGE_LOW)) == (1 << ENCODER_1_EDGE_LOW))
    {
        *ENCODER_1_INTR |= (1 << ENCODER_1_EDGE_LOW);
        if(lastTrigger==1)
        {
            if ((*GPIO_IN & (1 << ENCODER_2)) == (1 << ENCODER_2)) 
            { 
                encoderVal++;
                //encoderStickyIncrement++; 
            }
            else
            { 
                encoderVal--;
                //encoderStickyDecrement++;
            }
        }
        lastTrigger = 0;
    }
    else if ((*ENCODER_2_INTR & (1 << ENCODER_2_EDGE_HIGH)) == (1 << ENCODER_2_EDGE_HIGH))
    {
        *ENCODER_2_INTR |= (1 << ENCODER_2_EDGE_HIGH);
        if(lastTrigger == 0)
        {
            if ((*GPIO_IN & (1 << ENCODER_1)) == (1 << ENCODER_1)) 
            { 
                encoderVal++;
                if (encoderVal > encoderValOld+1)
                { 
                    encoderStickyIncrement++;
                    encoderValOld=encoderVal;
                    lastUsVal = currentUsVal;
                    currentUsVal = getTimeLW();
                }
            }
            else 
            { 
                encoderVal--;
                //encoderStickyDecrement++;
            }
        }
        lastTrigger = 1;
    }
    else if ((*ENCODER_2_INTR & (1 << ENCODER_2_EDGE_LOW)) == (1 << ENCODER_2_EDGE_LOW))
    {
        *ENCODER_2_INTR |= (1 << ENCODER_2_EDGE_LOW);
        if(lastTrigger == 0)
        {
            if ((*GPIO_IN & (1 << ENCODER_1)) == (1 << ENCODER_1)) 
            {
                encoderVal--;
                //encoderStickyDecrement++;
            } 
            else 
            {
                encoderVal++;
                //encoderStickyIncrement++;
            }
        }
        lastTrigger = 1;
    }
    else if ((*POWERSENSE_INTR & (1 << POWERSENSE_EDGE_LOW)) == (1 << POWERSENSE_EDGE_LOW))
    {
        *POWERSENSE_INTR |= (1 << POWERSENSE_EDGE_LOW);
        cs4270PowerDown();
    }

    // UI switches 
    for (uint8_t c=0;c<3;c++)
    {
        switchIntAddress = (uint32_t*)(IO_BANK0_BASE + IO_BANK0_INTR0_OFFSET + (((4*switchPins[c]) & 0xFFE0) >> 3)); 
        if ((*switchIntAddress & (1 << (((4*switchPins[c]) & 0x1F)+3))) == (1 << (((4*switchPins[c]) & 0x1F)+3)))
        {
            *switchIntAddress |= (1 << (((4*switchPins[c]) & 0x1F)+3));
            if (oldTickSwitches[c] + ROTARY_ENCODER_DEBOUNCE < getTickValue())
            {
                switchVals[c] &= ~(1 << 2);
                switchVals[c] |= (1 << 1);
                oldTickSwitches[c]=getTickValue();
            }
        }
        else if ((*switchIntAddress & (1 << (((4*switchPins[c]) & 0x1F)+2))) == (1 << (((4*switchPins[c]) & 0x1F)+2)))
        {
            *switchIntAddress |= (1 << (((4*switchPins[c]) & 0x1F)+2));
            if (oldTickSwitches[c] + ROTARY_ENCODER_DEBOUNCE < getTickValue())
            {
                switchVals[c] |= ((1 << 2) | (1 << 0));
                oldTickSwitches[c]=getTickValue();
            }
        }
    }


}
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

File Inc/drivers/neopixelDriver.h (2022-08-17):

/*
 * led_timer.h
 *
 *  Created on: Jul 27, 2021
 *      Author: philipp
 */




#ifndef LED_TIMER_H_
#define LED_TIMER_H_

#include <stdint.h>
#include "system.h"

#ifdef STM32
typedef struct {
	volatile uint32_t CR1;
	volatile uint32_t CR2;
	volatile uint32_t SMCR;
	volatile uint32_t DIER;
	volatile uint32_t SR;
	volatile uint32_t EGR;
	volatile uint32_t CCMR1;
	volatile uint32_t CCMR2;
	volatile uint32_t CCER;
	volatile uint32_t CNT;
	volatile uint32_t PSC;
	volatile uint32_t ARR;
	volatile uint32_t reserved;
	volatile uint32_t CCR1;
	volatile uint32_t CCR2;
	volatile uint32_t CCR3;
	volatile uint32_t CCR4;
	volatile uint32_t reserved1;
	volatile uint32_t DCR;
	volatile uint32_t DMAR;
} TIM23TypeDef;

typedef struct {
	volatile uint32_t CCR;
	volatile uint32_t CNDTR;
	volatile uint32_t CPAR;
	volatile uint32_t CMAR;
	volatile uint32_t reserved;
} DMAChannelTypeDef;

typedef struct {
	volatile uint32_t ISR;
	volatile uint32_t IFCR;
	DMAChannelTypeDef CHANNEL[7];
} DMATypeDef;

typedef struct {
	volatile uint32_t MODER;
	volatile uint32_t OTYPER;
	volatile uint32_t OSPEEDR;
	volatile uint32_t PUPDR;
	volatile uint32_t IDR;
	volatile uint32_t ODR;
	volatile uint32_t BSRR;
	volatile uint32_t LCKR;
	volatile uint32_t AFRL;
	volatile uint32_t AFRH;
	volatile uint32_t BRR;

} GPIOTypeDef;

typedef struct {
	volatile uint32_t CR;
	volatile uint32_t CFGR;
	volatile uint32_t CIR;
	volatile uint32_t APB2RSTR;
	volatile uint32_t APB1RSTR;
	volatile uint32_t AHBENR;
	volatile uint32_t APB2ENR;
	volatile uint32_t APB1ENR;
	volatile uint32_t BDCR;
	volatile uint32_t CSR;
	volatile uint32_t AHBRSTR;
	volatile uint32_t CFGR2;
	volatile uint32_t CFGR3;

} RCCTypeDef;

typedef struct {
	volatile uint32_t ACR;
	volatile uint32_t KEYR;
	volatile uint32_t OPTKEYR;
	volatile uint32_t SR;
	volatile uint32_t CR;
	volatile uint32_t AR;
	volatile uint32_t OBR;
	volatile uint32_t WRPR;
} FlashTypeDef;

typedef struct {
	volatile uint32_t CR1;
	volatile uint32_t CR2;
	volatile uint32_t OAR1;
	volatile uint32_t OAR2;
	volatile uint32_t TIMINGR;
	volatile uint32_t TIMEOUTR;
	volatile uint32_t ISR;
	volatile uint32_t ICR;
	volatile uint32_t PECR;
	volatile uint32_t RXDR;
	volatile uint32_t TXDR;
} I2CTypeDef;

// GPIO bits
#define INPUT (0)
#define OUTPUT (1)
#define AF (2)
#define ANALOG (3)

// RCC bits
#define PLLON (24)
#define PLLRDY (25)
#define CSSON (19)
#define HSIRDY (1)
#define HSION (0)
#define PLLNODIV (31)
#define PLLMULT (18)
#define PLLSRC (15)
#define PPRE2 (11)
#define PPRE1 (8)
#define SWS (2)
#define SW (0)
#define I2C1EN (21)

// Flash bits
#define LATENCY (0)
#define FLASH_BSY (0)
#define FLASH_PER (1)
#define FLASH_STRT (6)
#define FLASH_EOP (5)
#define FLASH_LOCK (7)
#define FLASH_PG (0)

#define CEN (0)
#define OC1M (4)
#define OC1PE (3)
#define OC1FE (2)
#define ARPE (7)
#define TIM2EN (0)
#define TIM3EN (1)
#define IOPAEN (17)
#define IOPBEN (18)
#define DMA1EN (0)
#define PINA0POS (0)
#define PINA9POS (9)
#define UIE (0)
#define CC1DE (9)
#define UDE (8)

// DMA CCR bits
#define MEM2MEM (14)
#define PL (12)
#define MSIZE (10)
#define PSIZE (8)
#define MINC (7)
#define PINC (6)
#define CIRC (5)
#define DIR (4)
#define TEIE (3)
#define HTIE (2)
#define TCIE (1)
#define EN (0)

// I2C bits
#define RXIE (2)
#define OA1EN (15)

#define RCC ((RCCTypeDef*)0x40021000UL)
#define GPIOA ((GPIOTypeDef*)0x48000000UL)
#define GPIOB ((GPIOTypeDef*)0x48000400UL)
#define TIM2 ((TIM23TypeDef*)0x40000000UL)
#define TIM3 ((TIM23TypeDef*)0x40000400UL)
#define DMA ((DMATypeDef*)0x40020000UL)
#define NVIC_ISER0 ((volatile uint32_t*)0xE000E100UL)
#define NVIC_ISER1 ((volatile uint32_t*)0xE000E104UL)
#define NVIC_ICER1 ((volatile uint32_t*)0xE000E184UL)
#define FLASH ((FlashTypeDef*)0x40022000UL)
#define I2C1 ((I2CTypeDef*)0x4000400UL)

// if timer 2 is not running, i.e. data transfer is over
#define READY_TO_SEND (TIM2->CR1 & 1) != 1
// data has been sent, now just waiting for the remaining time to elapse
#define WAIT_STATE TIM2->ARR > WS2818_CNT
#endif

#ifdef HARDWARE
void initNeopixels();
void decompressRgbArray(RGBStream * frame,uint8_t length);
void sendToLed();
uint8_t getSendState();
void setSendState(uint8_t s);

extern uint32_t clr_cnt;
extern uint32_t bit_cnt;
extern uint8_t * rawdata_ptr;

#define SEND_STATE_INITIAL 0
#define SEND_STATE_DATA_READY 5
#define SEND_STATE_RTS 1
#define SEND_STATE_SENDING 2
#define SEND_STATE_SENT 3
#define SEND_STATE_BUFFER_UNDERRUN 4
#endif

void setEngineState(uint8_t); // enginestate gets called by the task manager therefore it must be mocked for the hardware independent tests
uint8_t getEngineState();

#endif

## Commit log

2022-08-21 added schematic
    [rp2040_schematic.fzz]
2022-08-24 extracted switch definitions to rp2040_registers
2022-08-29 i2c
    defined pins and fixed pin function definition
2022-08-30 wm8731 driver
    added error indication by debug led
    [wm8731.h]
2022-08-30 i2*-interfaces and launch configs
    bugfixes for the i2*-interfaces, added raspberry pi debug launch config
2022-08-30 coreections: i2c7wm8731 driver
2022-08-30 adapted pio driver for wm8731
    plus minor fixes
2022-08-31 wm8731 driver done!
    [rp2040_schematic.fzz]
2022-10-29 cherrypick: added schematic
    [guitarpreamp.kicad_pcb, guitarpreamp.kicad_sch]
2022-10-30 work on schematics
    [guitarpreamp.kicad_pcb, guitarpreamp.kicad_sch]
2022-10-31 schematics
    * moved fritzing schematics to schematics folder
    * updated pcb
    * adapted gitignore
    [guitarpreamp.kicad_pcb, guitarpreamp.kicad_sch, rp2040_schematic.fzz]
2022-10-31 i2s driver
    set output to zeros after clocking out 16 bits
    to be compatible with 24bit-devices
2022-11-02 audio processing to irg handler
    audio processing part moved directly to the irq handler
    plus minor changes (reduced adc rate, stabilized pio driver)
    [core1Main.c, main.c]
2022-11-23 changes in filter_calculations
    using q14 instead of q15
2022-11-23 gui fixes cherry-picked from stm32f446
2022-11-30 cs4270 board
    driver and custom board based on cs4270 developed&tested
    it finally works!!
2022-11-30 corrected some design mistakes
    * connected oscillator enable to reset
    * attached DGND
    [guitarpreamp.kicad_pcb, guitarpreamp.kicad_sch]
2022-12-05 changed regulators, added design fixes
    [guitarpreamp.kicad_pcb, guitarpreamp.kicad_sch]
2022-12-08 cherrypick: chrous improvements
    interpolated sine chorus taken from stm32 branch
2022-12-08 added sticky bits to indicate button actions
2022-12-11 added sticky bit handling for the encoder
2022-12-14 changed cab values
    [guitarpreamp.kicad_pcb, guitarpreamp.kicad_sch]
2022-12-14 added simulation for the preamp
    [guitarpreamp_sim.kicad_pcb, guitarpreamp_sim.kicad_sch]
2022-12-30 USB Enumeration correct!
    * added debug output
    * BUGFIX: reset pid for all setup requests
2023-01-03 usb driver reordering
    separated cdc-specific functions from common usb functions
2023-01-04 partial work on usb msc driver
2023-01-06 cdc driver: functional fix after refactoring
    [main.c]
2023-01-07 partial buxfixes for the msc device
2023-01-09 MSC DRIVER WORKS!!
2023-01-10 USB MSC DRIVER DONE
    * added zero-termination option for multipacket transfer
    * removed adapted tiny usb driver
    * fixed issues with the scsi write10 command
    [main.c]
2023-01-22 added bass samples
    tribute to geezer butler, duff mcCagan and Steve Harris ;-)
2023-01-24 fixed 2nd order iir filter implementation!
2023-01-25 iir filters
    * modified optimization in cab modeling
    * removed unused parameters in 2nd order iir filter
    * replaced parameters in the cab models
2023-02-03 amp model 1 update
    * added analog delay (lowpass in feedback loop)
    * fixed cab sim filter coefficients
2023-02-03 allpass filter & reverbs
    * added saturation logics to allpass
    * changed signal levels in reverb 2
2023-02-12 added clipping indicators
    [rp2040_schematic.fzz]
2023-02-17 added schematic for the mic&stomp extension board
    [mic_extension_board.kicad_pcb, mic_extension_board.kicad_sch]
2023-02-17 started firmware for stomp/led controller
2023-02-19 added debouncer for stomp switches
2023-02-19 corrected ic footprints, shrinked
    [mic_extension_board.kicad_pcb, mic_extension_board.kicad_sch]
2023-02-19 update reverb
    * added 4 parameters sets
    * added simple lowpass filter in delay loop
    * extended scripting tool to calculate delay and feedback times
2023-02-22 numerical work on filters...
2023-02-24 extracted common reverb stuff into utils
    * common stuff is allpass filter and hadamard diffusor
2023-02-26 added headphone amp
    [mic_extension_board.kicad_pcb, mic_extension_board.kicad_sch]
2023-02-26 imported the unit pulse generation tool
    from the stm32 branch
2023-02-28 added basic stomp switch support
    * changes amoong known programs
    * no lights supporzt so far
2023-02-28 stomp switch support
    now the switch actually changes the program
2023-03-04 implemented audio engine shutdown on power outage
    * power down cs4270 when powersense pin is low
    * rearranged pin definitions
2023-03-04 update mic expansion board
    the design is now symmetric to the greatest extent, reduces cost
    and nasty switch on/off behaviour
    [mic_extension_board.kicad_pcb, mic_extension_board.kicad_sch]
2023-03-11 last changes before order
    * fixed last minor details
    * tidied gitignore files
    [mic_extension_board.kicad_pcb, mic_extension_board.kicad_sch]
2023-04-10 expansio board firmware
    * added settings for avr gcc
    * fixed minor bug
    [mic_extension_board.kicad_pcb, mic_extension_board.kicad_sch]
2023-04-11 corrected avr device, flashing works!
2023-04-14 various correctios
    moved rotary/button interrupts to proc1
    rotated display software-wise
    [rotEncoderSwitchPower.c]
2023-04-14 stomp switch board working!
2023-04-21 cherry pick:display driver improvements
    bugfix in setcursor
    performance improvement when drawing text
2023-04-21 v2! with extension board
    first demoable version including the extension board
2023-04-23 added driver for 24lc128 (not yet tested)
2023-04-26 program switching is now noiseless!
    [core1Main.c, main.c]
2023-04-28 graphics update
    * added fonts
    * changed internal bitmap format to x first
    * added dma-driven display routines
2023-04-30 audio: reset function
    added reset functions for all time-dependent audio processors
    [core1Main.c]
2023-05-07 ui extensions
    * structural change: every program sets the raw parameter value on callback
    * corrected inclusion of the gfx fonts
    * added ui levels for handling and editing presets
    * structural change: handling switching ui page automatically
    [main.c]
2023-05-07 update schematic to kicad 7
2023-05-17 grand ui remake
    added preset handling: changing, editing and saving
    minor correction to the display driver allowing easier switch
    from SH1106 to SSD106/SSD1309
2023-05-21 component diagram / masterplan
    added diagram explaning how to wire the individual boards
    based on extensive experimentation and testing
2023-06-13 async display
    async display fixed (enable dma was missing)
2023-06-13 i2c adressing
    added adress change when switching from eeprom to stomp extension board
2023-06-13 startup debug info
    make one led light up to ensure
    that the extension board is listening on i2c
2023-06-15 stompswitch-related ui fixes
    * corrected i2c read routine
    * corrected preset assignment upon entering lvl3
    * Footswitch Action is upon release
    [core1Main.c]
2023-06-15 schematic: changed some footprints & fixed errors
    [mic_extension_board.kicad_pcb]
2023-06-16 bugfix: encoder only working in one direction
2023-06-17 two type of bwImageStructs
    added two version of bwImageStruct optimized for display using
    the SSD1306 driver or copying into a display buffer
2023-06-23 i2c transmit should now be truly blocking
2023-06-23 extended cs4270 driver
    * muting of individual channels
    * setting output volume
2023-06-25 i2c master transmit
    wait for stop detected and tx fifo empty
    now master transmit should be truly blocking
2023-06-29 system settings
    i2c driver changed (wait for stop detected)
    ensure correcte i2c address for each device on the bus
2023-07-10 added speed measurement for rotary encoder
2023-07-10 firmware update options
    disable picoboot interface, define lower led as activity for usb drive
2023-07-28 bugfix:
    gain of high gain model editable using encoder
2023-10-19 support 64*128 (vertical) displays as well
    * graphics in uiLevels 0-2 are framebuffer based as well
    * defined resolution as precompiler vars
2023-10-22 extension board
    fixed and adapted makefile for
    extension board firmware
2023-10-22 multi display support
    added configureable support for ssd1306, sh1106 and sh1107 displays
    currently active configuration is sh1106 in horizontal config
    [mic_extension_board.kicad_sch]
2023-10-29 ui fixes
    fixed error due to changes to framebuffered operation
2023-10-29 oled driver parametrization
    more parametrization to allow easy adapation to
    various driver and mounting options
2023-11-23 moved includes related to driver into a subfolder
2023-11-23 bugfixes
    * more rigid check upon loading presets
    (mitigates crashes due to non-match presets and firmware versions)
    * corrected preprocessor flag
    [core1Main.c]
2023-11-24 reduced #samples per parameter @ integration tests
